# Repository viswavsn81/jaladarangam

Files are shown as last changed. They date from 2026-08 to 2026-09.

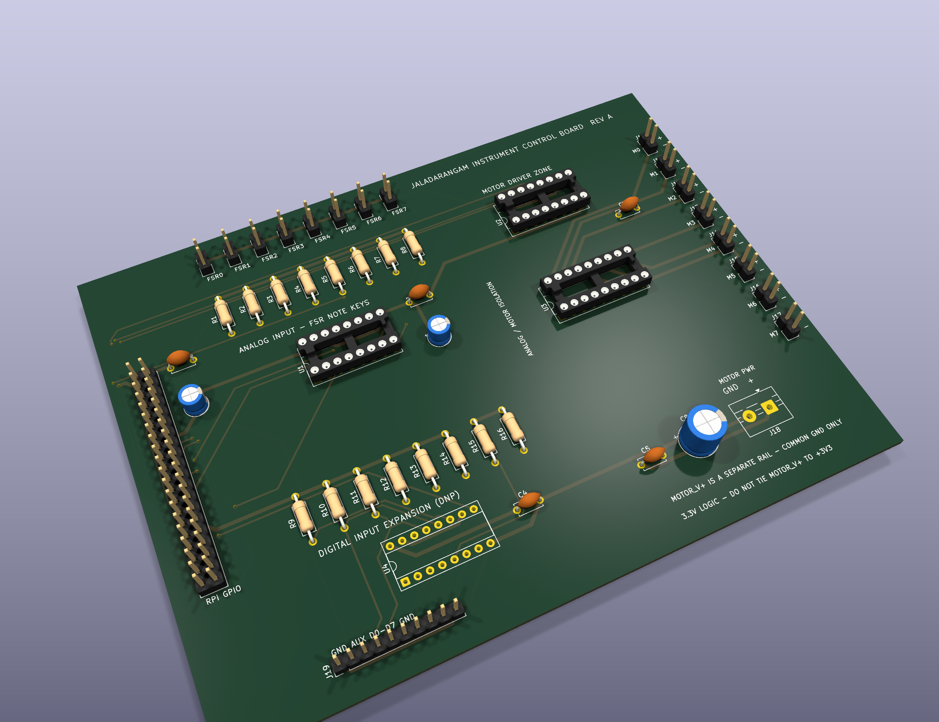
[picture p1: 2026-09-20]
hardware/review/pcb_3d_iso.png

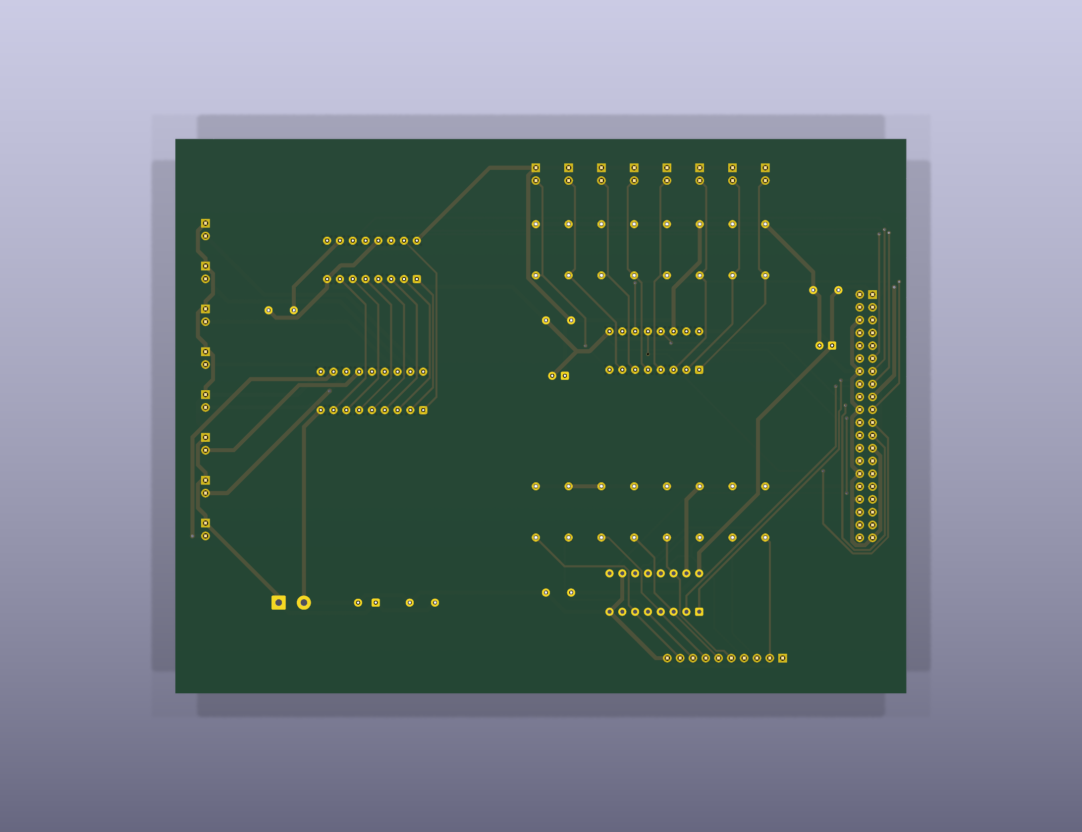
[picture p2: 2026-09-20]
hardware/review/pcb_3d_bottom.png

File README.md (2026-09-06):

# Mindfulness Instrument

A Raspberry Pi 3 project that plays an instrument sample when a sensor is triggered.
Started as a keyboard-spacebar proof of concept (evdev + pygame); the wiring below is
for the real sensor hardware: 8 FSR402 force sensors, one per note key (Sa through
upper Sa), read through an MCP3008 ADC over SPI. An earlier hardware iteration used
2 FSRs plus a SparkFun SoftPot ribbon for continuous glide; that layout was replaced
by the 8 discrete note keys below, and the SoftPot has since been removed entirely.

The project's original design called for two MCP3008 chips sharing one SPI0 bus
(distinguished by chip-select line): **ADC1** for the 8 note-key FSRs, and **ADC2**
for the gamakam/octave-up/octave-down control keys. ADC1 is documented and wired
below and is the only MCP3008 in the current build. **ADC2 was built, found to
have an unresolved hardware fault, and has been fully replaced** by an Arduino
Nano 33 BLE reading the three control keys directly over USB serial — see
[STATUS.md](STATUS.md) for the current project state and [ADC2 (control keys)](#adc2--control-keys)
below for the (now superseded) ADC2 wiring record.

## Hardware

- Raspberry Pi 3 Model B
- 2x MCP3008 8-channel 10-bit ADC (16-pin DIP, SPI interface) — ADC1 (note keys,
  wired) and ADC2 (control keys, being wired)
- 8x FSR402 round force sensor (18mm) — ADC1's discrete note keys, CH0-CH7 =
  Sa, Ri, Ga, Ma, Pa, Da, Ni, Sa' (upper Sa)
- Resistors: 8x 10kΩ (ADC1, one per note-key FSR) — plus 1x 10kΩ per ADC2
  control-key FSR as those get populated
- Breadboard + jumper wires

## Wiring

All physical pin numbers below refer to the Raspberry Pi's 40-pin GPIO header, and were
verified against the official Raspberry Pi pinout and the Microchip MCP3008 datasheet
(DS20001295E) before wiring.

### Pi -> MCP3008 (ADC1)

| Pi physical pin | Signal | MCP3008 pin |
|---|---|---|
| 1 | 3.3V | 16 (VDD) |
| 1 | 3.3V | 15 (VREF) |
| 6 | GND | 14 (AGND) |
| 6 | GND | 9 (DGND) |
| 23 | GPIO11 / SPI0 SCLK | 13 (CLK) |
| 19 | GPIO10 / SPI0 MOSI | 11 (DIN) |
| 21 | GPIO9 / SPI0 MISO | 12 (DOUT) |
| 24 | GPIO8 / SPI0 CE0 | 10 (CS/SHDN) |

MCP3008 pin 1 (CH0) is at the end of the chip marked with a notch/dot — make sure that
end is oriented correctly on the breadboard before inserting.

### Note-key channel assignment (ADC1)

| MCP3008 pin (channel) | Note key |
|---|---|
| 1 (CH0) | Sa |
| 2 (CH1) | Ri |
| 3 (CH2) | Ga |
| 4 (CH3) | Ma |
| 5 (CH4) | Pa |
| 6 (CH5) | Da |
| 7 (CH6) | Ni |
| 8 (CH7) | Sa' (upper Sa) |

All 8 are discrete FSR keys, matching `jaladarangam.py`'s `LIVE_POSITIONS =
set(range(8))`. There is no SoftPot or continuous-glide sensor in the current
hardware — an earlier prototype iteration used a SoftPot ribbon on CH2 for
continuous pitch glide, but that approach was replaced by these 8 discrete FSR
keys and the SoftPot has been physically removed.

### Sensors (voltage dividers into ADC1)

Identical divider pattern for all 8 note-key FSRs:

| Component | Leg/end | Connects to |
|---|---|---|
| Note-key FSR | leg A | 3.3V rail |
| Note-key FSR | leg B | ADC1 channel pin (per the table above) **and** 10kΩ resistor -> GND |

The 10kΩ resistor forms a voltage divider: FSR resistance drops under pressure,
so the sense-node voltage *rises* with force.

## Step-by-step wiring order (ADC1)

1. Power off / unplug the Pi before wiring anything.
2. Seat the MCP3008 across the breadboard's center gap, pin 1 (notch end) toward CH0.
3. Run the 3.3V rail and GND rail down the breadboard from the Pi's pin 1 and pin 6.
4. Wire MCP3008 VDD (16) and VREF (15) to the 3.3V rail; AGND (14) and DGND (9) to the GND rail.
5. Wire the SPI lines: Pi pin 23 -> MCP3008 CLK (13), Pi pin 19 -> DIN (11),
   Pi pin 21 -> DOUT (12), Pi pin 24 -> CS/SHDN (10).
6. Wire each of the 8 note-key FSRs (Sa through Sa', MCP3008 channels CH0-CH7 per
   the channel-assignment table above): one leg to the 3.3V rail, the other leg to
   its assigned MCP3008 channel pin and to one leg of a 10kΩ resistor whose other
   leg goes to the GND rail. Repeat for all 8 keys.
7. Double-check every connection against the tables above before powering the Pi back on.
8. Once wired, enable SPI on the Pi (`sudo raspi-config nonint do_spi 0`) if not already
   enabled, then reboot before trying to read the MCP3008.

## ADC2 (control keys) — SUPERSEDED, kept for historical/wiring reference only

**This entire section describes an abandoned hardware path.** ADC2 was
physically wired per the plan below, then extensively fault-tested (FSR
swaps, pulldown/ground checks, chip-select swaps, physical chip swaps) after
every channel — including one never wired to anything — read an identical
fixed value no matter what changed. That combination of tests pointed at the
MCP3008 chip/circuit itself, not the wiring, so ADC2 was retired rather than
debugged further. **The three control keys (gamakam, octave+, octave-) are
now read by an Arduino Nano 33 BLE over USB serial instead** — see
[STATUS.md](STATUS.md) and `control_keys/control_keys.ino`. No code in this
repo reads ADC2/CE1. The wiring plan below is left intact only as a record
of what was built and why it didn't work, in case the physical MCP3008/
breadboard setup is ever revisited.

ADC2 is a second MCP3008 sharing the same SPI0 bus as ADC1 (same CLK/DIN/DOUT,
same power/ground rails), distinguished by its own hardware chip-select line
(CE1 instead of ADC1's CE0). It carries the three control keys — gamakam,
octave+, octave- — reserved from the original two-chip instrument design.

### Shared bus (Pi -> ADC2)

Identical to ADC1's bus wiring above — these four signals are shared by both
chips; do not re-run separate jumpers from the Pi for these, just tie ADC2's
matching pins onto the same rails/lines ADC1 already uses.

| Pi physical pin | Signal | MCP3008 pin |
|---|---|---|
| 1 | 3.3V | 16 (VDD) |
| 1 | 3.3V | 15 (VREF) |
| 6 | GND | 14 (AGND) |
| 6 | GND | 9 (DGND) |
| 23 | GPIO11 / SPI0 SCLK | 13 (CLK) |
| 19 | GPIO10 / SPI0 MOSI | 11 (DIN) |
| 21 | GPIO9 / SPI0 MISO | 12 (DOUT) |

### ADC2-specific: chip select

| Pi physical pin | Signal | MCP3008 pin |
|---|---|---|
| 26 | GPIO7 / SPI0 CE1 | 10 (CS/SHDN) |

This is distinct from ADC1's chip-select (Pi physical pin 24, GPIO8 / SPI0 CE0)
— CE0 and CE1 are separate hardware-controlled pins, so make sure ADC2's
CS/SHDN goes to physical pin 26 (GPIO7/CE1), not physical pin 24 (GPIO8/CE0),
which is already committed to ADC1.

### Channel assignment (reserved from the original design)

| MCP3008 pin (channel) | Control key | Status |
|---|---|---|
| 1 (CH0) | gamakam | unpopulated — currently a keyboard-spacebar stand-in in software |
| 2 (CH1) | octave+ | unpopulated |
| 3 (CH2) | octave- | unpopulated |
| 4-8 (CH3-CH7) | spare/unused | reserved for future use, not currently assigned |

### Sensors (voltage dividers into ADC2) — apply per channel as each FSR is added

Same pattern as ADC1's note-key FSRs: for whichever of the three control
channels above has an FSR physically attached, wire it as follows. Do **not**
wire a channel this way until an FSR is actually being installed on it —
until then, leave that channel's row in the table above as "unpopulated."

| Component | Leg/end | Connects to |
|---|---|---|
| Control-key FSR | leg A | 3.3V rail |
| Control-key FSR | leg B | ADC2 channel pin (CH0/CH1/CH2 per the table above) **and** 10kΩ resistor -> GND |

### Step-by-step wiring order (ADC2)

1. Power off / unplug the Pi before wiring anything.
2. Seat the second MCP3008 on the breadboard, pin 1 (notch end) toward CH0, same
   orientation convention as ADC1.
3. Tie ADC2's VDD (16) and VREF (15) onto the existing 3.3V rail; AGND (14) and
   DGND (9) onto the existing GND rail (the same rails ADC1 already uses).
4. Tie ADC2's CLK (13), DIN (11), and DOUT (12) onto the same SPI0 SCLK/MOSI/MISO
   lines ADC1 already uses (Pi physical pins 23/19/21) — these lines are shared,
   not duplicated.
5. Wire ADC2's CS/SHDN (10) to Pi physical pin 26 (GPIO7 / SPI0 CE1) — a new,
   ADC2-only line, separate from ADC1's CE0 on physical pin 24.
6. For each control-key FSR you are physically installing now, wire it per the
   voltage-divider table above into its assigned channel; leave any channel with
   no FSR yet unpopulated rather than wiring a dangling divider.
7. Double-check every connection against the tables above before powering the Pi
   back on, and update the status line at the top of this section to reflect
   exactly which channels are now populated.
8. SPI0 is already enabled from the ADC1 setup; no additional `raspi-config`
   step is needed for a second chip on the same bus.

## Software

- `spacebar_instrument.py` — the keyboard-spacebar proof of concept (evdev + pygame),
  kept as a reference/fallback trigger while the sensor wiring above is being built out.
- `samples/guitar_note.wav` — CC0 guitar sample from OpenGameArt.org
  (https://opengameart.org/content/guitar-0), used by the spacebar PoC.
- `read_fsr_raw.py` — prints raw MCP3008 readings for a channel; used to verify a
  sensor's wiring/divider orientation before building anything on top of it.
- `fsr_oscillator.py` — maps FSR1 (CH0) and FSR2 (CH1) each to a persistent sine
  oscillator (pygame.mixer, 48000Hz/1024-sample buffer) whose pitch tracks pressure;
  an interface-level proof of concept, not the final instrument sound.
- `gamaka.py` — the pressure-controlled pitch-bend (gamaka) proof of concept. FSR1
  triggers/bends a D3 guitar pluck, FSR2 triggers/bends a G3 pluck. Samples are
  streamed through a `sounddevice` callback with a variable-rate linear-interpolation
  reader per voice (pygame.mixer can't vary playback speed live, hence the different
  library here vs. the oscillator above). Raw ADC is EMA-smoothed before driving the
  bend; a fresh pluck triggers on the raw touch-threshold crossing, and the bend
  (0 to +40 cents, `rate = 2^(cents/1200)`) tracks the smoothed value continuously,
  including after release, so pitch settles back down instead of snapping.
- `prepare_samples.py` — one-time preprocessing script that derived `d3_pluck.wav`
  and `g3_pluck.wav` from the source samples below.
- `samples/d3_pluck.wav`, `samples/g3_pluck.wav` — derived from
  [`karoryfer.shinyguitar`](https://github.com/sfzinstruments/karoryfer.shinyguitar)
  (CC0 1.0, verified directly against the repo's `LICENSE` file). That library samples
  in whole tones rather than every semitone, so D3 and G3 aren't recorded directly —
  they're derived from the nearest neighbors (Eb3 and Gb3) via a 1-semitone pitch
  shift, resampled to 48000Hz to match this Pi's PipeWire audio graph quantum.
- `jaladarangam.py` — the current real hardware-driven instrument. Reads all 8
  physical note-key FSRs on ADC1 (CH0-CH7 = Sa..Sa'), with raga-selectable
  positional layout (`--raga`), polyphony (up to 8 notes ringing
  independently), mandolin/guitar/flute instrument switching with
  per-instrument envelopes (flute stops promptly on release; mandolin/guitar
  ring through their natural decay), octave-aware jaru (glide) and octave-
  nearest note selection, gamakam/octave+/octave- read from an Arduino Nano
  33 BLE over USB serial (see `control_keys/control_keys.ino`), odukkal
  (pressure-to-pitch-bend, toggleable), attack velocity, the double bass
  drone, a live 3-band EQ, master volume, and dual I2S+headphone output. All
  of the above is controllable via typed stdin commands, a WiFi WebSocket
  server (port 8765), and a Bluetooth Classic SPP connection (no PIN
  pairing) — all three dispatch through the same command layer, both
  network transports run persistently via systemd
  (`systemd/jaladarangam.service`), and both are documented in full in
  **[PROTOCOL.md](PROTOCOL.md)** (the contract for building a remote-control
  app against). Known limitation: a tanpura drone was scoped
  but is **not implemented** (no CC0/permissive-license sample could be
  sourced that was also actually downloadable — a Freesound recording was
  gated behind account login, and a Pixabay mirror of it was blocked by
  Cloudflare bot-protection from this environment's tools). Usage:
  `python3 jaladarangam.py --raga Shankarabharanam`.

### Control-key software support (superseded — now via Arduino Nano, not ADC2)

`jaladarangam.py` reads only ADC1 (CE0) for note keys — no code in this repo
opens or reads ADC2 (CE1) at all, since ADC2 was retired (see above). The
gamakam/octave+/octave- control keys are real hardware today, but read from
an Arduino Nano 33 BLE over USB serial (`poll_nano_values`), not from ADC2 or
any keyboard stand-in. See [STATUS.md](STATUS.md) for the current summary and
`control_keys/control_keys.ino` for the Nano's own firmware.

`gamaka.py`, `read_fsr_raw.py`, and `fsr_oscillator.py` each open a single
spidev bus (ADC1/CE0 only) with no CE1/ADC2 handling, and are unrelated to
`jaladarangam.py`'s Nano integration. The keyboard-based prototypes
(`sliding_window_raga.py`, `gamaka_keyboard.py`, `gamaka_keyboard_mixer.py`)
stand in for control keys with keyboard input (e.g. spacebar for gamakam,
bracket keys for octave up/down) and don't touch spidev at all — these are
separate, earlier scripts, left unchanged.

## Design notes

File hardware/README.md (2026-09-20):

# Jaladarangam Instrument Control Board

KiCad 10 project for the instrument's control board: a Raspberry Pi 3 reads 8
analog FSR note keys through an MCP3008 SPI ADC, and drives 8 vibration motors
through a 74HC595 shift register feeding a ULN2803A Darlington array. A 74HC165
is fitted as a socketed but unpopulated digital-input expansion.

Logic runs at 3.3 V. **MOTOR_V+ is a separate supply rail** sharing only GND
with the logic domain — it is never tied to +3V3.

Board: 145 × 110 mm, 2 layers, through-hole throughout, all four ICs socketed.

## Everything is generated from one file

`scripts/board_spec.py` is the single source of truth: components, pin-to-net
assignments, schematic and PCB placement, design rules and net classes. The
schematic, PCB, project file and BOM are all generated from it, so there is no
second place for the wiring to drift.

Nothing here is hand-edited. To change the board, change `board_spec.py` and
re-run the pipeline.

```
scripts/build.sh     board_spec -> .kicad_pro -> .kicad_sch -> .kicad_pcb -> .dsn
scripts/route.sh     autoroute, import the session, DRC, zone check
scripts/fab.sh       gerbers, drill files, BOM
scripts/make_review.sh   3D renders, 2D layout, silkscreen close-ups -> review/
```

The order in `build.sh` matters. `make_project_file.py` writes the net classes
into the `.kicad_pro`; `gen_pcb.py` then **binds that project to the board**
before saving. A bare `pcbnew.BOARD()` carries KiCad's built-in defaults (one
0.2 mm class), and saving such a board writes those defaults straight over the
project file — which is exactly how the MOTOR_V+ Power class was silently lost
once. `gen_pcb.py` now refuses to write a board whose net classes are wrong.

## Verification

Each stage is checked independently rather than trusted:

| Check | What it proves |
|---|---|
| `board_spec.sanity_check` | No duplicate refs, no single-pad nets, MOTOR_V+ and +3V3 share no pad, divider/driver/aux nets have the right pad counts, every polarity mark agrees with the net on its pad |
| `verify_polarity.py` | Every silkscreen polarity mark sits nearest the pad it names, and that pad carries the net the mark asserts |
| `kicad-cli sch erc` | KiCad's own electrical rules — 0 violations |
| `verify_netlist.py` | KiCad's exported netlist matches `board_spec` pad-for-pad, and every deliberately open pin is accounted for |
| `verify_netclasses.py` | The DSN handed to the router really carries 0.8 mm on the motor rail and 0.4 mm on signals |
| `import_ses.py` | Track widths that actually landed on copper match their net class |
| `kicad-cli pcb drc` | 0 violations, 0 unconnected |
| `verify_zones.py` | Motor and analog copper stayed in their own zones after routing |

## Review images

`review/` is the single home for reviewable output - schematic and board, PDF
and PNG - so the design can be looked at without opening KiCad. It regenerates
with `scripts/make_review.sh`:

| File | What it shows |
|---|---|
| `schematic.pdf` | Full schematic, vector - the one to read properly |
| `schematic.png` | Same sheet at 300 dpi, for a quick look |
| `pcb_routed.pdf` | Routed board, vector |
| `pcb_3d_iso.png` | 3D isometric with component bodies |
| `pcb_3d_top.png` / `pcb_3d_bottom.png` | 3D straight-on, both sides |
| `pcb_2d_layout.png` | 2D layout: both copper layers, silkscreen, outline |
| `pcb_silkscreen.png` | Silkscreen + board outline only, no copper |
| `silk_fsr_headers.png` | Close-up: FSR note-key headers J2-J9 |
| `silk_motor_headers.png` | Close-up: motor headers J10-J17 |
| `silk_motor_power.png` | Close-up: motor supply input J18 |
| `silk_aux_header.png` | Close-up: AUX digital input header J19 |
| `silk_pi_header.png` | Close-up: Raspberry Pi GPIO header J1 |

The silkscreen views plot `F.Silkscreen` and `Edge.Cuts` only, in black and
white - no copper behind the captions, and far better contrast than KiCad's
silkscreen yellow on a white page. `Edge.Cuts` is kept purely for orientation.

Crops come from the footprints themselves (`dump_regions.py` reads the board),
not hard-coded rectangles, so they stay correct if placement changes. KiCad's
`--page-size-mode 2` SVG carries a viewBox in board millimetres, so a crop is
just a narrowed viewBox rather than pixel arithmetic.

The schematic is one A2 sheet. PDF is the primary form because it stays vector
and a dense sheet reads at any zoom; the 300 dpi PNG is there for convenience.
The PNG step is driven by the PDF's actual page count, so extra sheets would be
exported as `schematic_p1.png`, `schematic_p2.png` rather than silently lost.

3D renders need the 3D model packages, which the lite AppImage omits;
`kienv.sh` points `KICAD10_3DMODEL_DIR` at a full KiCad extract when one is
present and warns if it is not. U4 renders as bare pads because KiCad hides
3D models for DNP parts - its socket is still fitted.

## Toolchain

No root, no paid services.

- **KiCad 10.0.6**, official AppImage in `/home/pyru/opt/kicad10`. Provides
  `kicad-cli` and a bundled `python3.11` with `pcbnew`.
- **FreeRouting 2.4.1** headless CLI in `/home/pyru/opt/freerouting`, via a
  Specctra DSN → SES round-trip.
- **Temurin JDK 25** in `/home/pyru/opt/jdk25` — FreeRouting's jar is
  class-file 69 and the system JDK is 21.

`scripts/kienv.sh` wires these together and keeps KiCad's config and library
tables inside `hardware/.kicad-config/`, so builds do not depend on any
developer's `~/.config/kicad` state.

## Layout

Signal flow runs left to right, with the two noisy domains held apart:

```
Pi header | analog input zone | << 14 mm empty corridor >> | motor driver zone
(left edge) (FSR headers top    (nothing routed across it   (motor headers
             edge, pulldowns,     but GND and +3V3)          right edge,
             MCP3008)                                        supply bottom)
                 |
   74HC165 expansion block (DNP) along the bottom edge
```

Every off-board connector is edge-accessible and captioned on silkscreen:
`FSR0-7`, `M0-7`, `MOTOR PWR`, `GND AUX D0-D7 GND`, `RPi GPIO`.

## Notes for assembly

- Fit all four IC sockets, **including U4's** — the 74HC165 itself is the only
  DNP part, so the expansion can be populated later with no rework. Its
  pulldowns (R9-R16) and header (J19) are populated.
- J19 is a 1×10: pins 1 and 10 are GND, pins 2-9 are D0-D7.
- Each FSR header is `+3V3` on pin 1, channel node on pin 2. The 10 k pulldown
  is on-board; the FSR forms the upper leg of the divider.
- Each motor header is `MOTOR_V+` on pin 1 (marked `+`), the ULN2803A output
  on pin 2 (marked `-`). Pin 1 is the rectangular pad, with the L-shaped silk
  corner beside it. Wire the motor's positive lead to `+`.
- J18 is marked `+` (MOTOR_V+) and `GND`. Getting it backwards would put the
  motor rail onto the board's ground net.
- `fab/bom.csv` includes the sockets and the off-board parts;
  `fab/bom_kicad.csv` is KiCad's own export of the schematic parts only.

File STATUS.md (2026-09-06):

# Project status (as of 2026-09-06)

A running snapshot of where this project actually is, for picking work back
up cleanly later. Hardware/wiring specifics live in `README.md`; the network
control JSON contract lives in `PROTOCOL.md`. This file is the "what's done,
what's not, what's next" summary.

## Hardware

- **ADC1 (MCP3008, SPI CE0)**: all 8 note keys (Sa through upper Sa, CH0-CH7)
  physically wired with real FSR402 sensors and confirmed working.
- **ADC2 is gone.** The originally-planned second MCP3008 for the three
  control keys had an unresolved hardware fault (every channel - including
  one never wired to anything - read an identical fixed value regardless of
  wiring, grounding, or which physical chip/chip-select line was used). It
  has been **fully replaced** by an Arduino Nano 33 BLE over USB serial,
  reading its own three analog FSRs directly: `A0`=gamakam, `A1`=octave+,
  `A2`=octave- (firmware: `control_keys/control_keys.ino`). No ADC2/CE1
  code remains in `jaladarangam.py`.

## Software (`jaladarangam.py`)

- **Polyphony**: up to 8 notes ring independently (was strictly
  monophonic). A key's own re-pluck replaces only its own prior voice.
- **Octave-nearest note selection** on normal plucks: Ri/Ga/Ma/Pa/Da/Ni land
  in whichever octave (default, one up, or one down) is nearest the last
  note played. **Sa and upper Sa are deliberately excluded** from this -
  they already have two dedicated keys (key 1 / key 8), and applying
  nearest-pitch there too would flip the traditional Ni->Sa cadence to
  resolve upward instead of down (the leading-tone-to-tonic gap is always
  the largest "improvement" nearest-pitch could find, so no distance-based
  rule can fix the Sa-adjacent case without also breaking this one - this
  was worked through explicitly rather than guessed). The manual
  octave+/octave- keys remain the override for any other case.
- **Odukkal** (pressure-to-pitch-bend while a key is held and ringing):
  toggle with `o`+Enter (stdin) or `toggle_odukkal` (network), default OFF.
  One-euro-filtered per voice, additive on top of jaru/octave-shift state.
- **Attack velocity**: always active (not gated by the odukkal toggle) -
  press speed scales pluck loudness.
- **Per-instrument envelope**: mandolin/guitar are "plucked" (ring through
  natural decay regardless of release - unchanged, original behavior).
  Flute is "sustained" - release stops the note promptly with a short
  (50ms) click-free fade instead of playing out its full recorded length.
  True crossfaded sample looping for the sustain portion was considered
  and deliberately not implemented (see `jaladarangam.py`'s module
  docstring for why - the samples' natural sustain region has real
  vibrato/breath variation that makes a blind loop point risky).
- **Network control**: every toggle/config command (drone, instrument
  source, EQ, dual output, odukkal, volume) is a standalone function
  callable from anywhere, dispatched identically regardless of transport.
  Two transports, both running now, both documented in full in
  `PROTOCOL.md`:
  - **WiFi**: WebSocket server on port 8765.
  - **Bluetooth**: Classic SPP/RFCOMM, standard Serial Port Profile UUID,
    "Just Works" pairing (no PIN). Built on BlueZ's own D-Bus API
    (`dbus-python` + PyGObject's `GLib`), not PyBluez (confirmed
    unmaintained - see `PROTOCOL.md`'s implementation notes).
  - Both transports run persistently via a `systemd --user` service
    (`systemd/jaladarangam.service`, with lingering enabled) - survives
    reboots, no terminal session required. stdin control still works
    identically alongside both.
  - Validated end-to-end with a real Android phone: paired with no PIN,
    connected via a generic SPP terminal app ("Serial Bluetooth
    Terminal"), sent `{"cmd": "toggle_drone"}`, confirmed the drone
    turned on and a simultaneously-connected WebSocket client saw the
    same state change broadcast immediately.

## Explicitly NOT yet done

- **Tanpura drone**: scoped early on, never implemented. No CC0/permissive-
  license sample could be found that was also actually downloadable
  (a Freesound CC0 recording was gated behind account login; a Pixabay
  mirror of it was blocked by Cloudflare bot-protection from available
  tooling). No `toggle_tanpura` command exists anywhere - there's no
  feature behind it to expose.
- **The Android app itself**: not started. `PROTOCOL.md` is written as its
  complete spec (every command, exact fields, the state-push shape, both
  transports) - manual testing so far has used a generic SPP terminal app
  and a Python WebSocket script standing in for it, not a real app.
- **Jaru direction coverage**: only Sa->Ri has been extensively
  bench-tested against real hardware; other key-to-key jaru pairs and
  octave-down landings are implemented (and now exercised more, thanks to
  polyphony/octave-nearest testing) but not as thoroughly verified.
- **Attack-velocity calibration**: the counts/sec thresholds
  (`VELOCITY_MIN/MAX_COUNTS_PER_SEC`) were recalibrated once against real
  press data during testing but are still a rough fit, not a precisely
  tuned curve - worth revisiting by ear if velocity response feels off.
- **CPU headroom**: checked informally under active multi-key play
  (~20% of one core on the Pi 3, comfortable) - never stress-tested with
  literally all 8 keys held simultaneously plus drone plus dual output,
  since that requires more hands/hardware than one person has.

## Next session: start here

**Build the Android app against `PROTOCOL.md`.** This session's entire
WiFi+Bluetooth effort was specifically to enable that, both transports are
now validated end-to-end with real (if generic) clients, and the protocol
doc is written to be a complete, standalone spec for exactly this. This is
offered as a recommendation, not a decision made on the user's behalf - say
if tanpura sourcing (or something else) should actually come first.

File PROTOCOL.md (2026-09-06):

# jaladarangam.py network control protocol

This is the contract for any client (Android app, browser dev console, test
script, Bluetooth SPP terminal app) controlling `jaladarangam.py` remotely.
The **same JSON command set and state-push shape** applies over both
transports below - only how the bytes get to/from the process differs.

## Transport 1: WiFi (WebSocket)

- URL: `ws://<pi-ip>:8765`
- The Pi's LAN IP is **not fixed** in this document on purpose - run
  `hostname -I` on the Pi to get its current address, or check the
  `[network] WebSocket server listening on ...` line the instrument prints
  at startup. Port `8765` is fixed.
- No authentication, no TLS. This is a local-network-only control channel -
  do not expose port 8765 outside your LAN (e.g. via router port-forwarding).
- Every message, both directions, is a single JSON object per WebSocket
  text frame (not newline-delimited, not batched).

## Transport 2: Bluetooth (Classic SPP / RFCOMM)

- Device name shown while scanning/pairing: **`Jaladarangam`** (this Pi's
  Bluetooth alias - not its hostname).
- Service: standard Serial Port Profile, UUID `00001101-0000-1000-8000-00805f9b34fb`,
  RFCOMM channel 1. Any generic Bluetooth SPP terminal app (Android or
  otherwise) that connects "by UUID" (the normal way - `BluetoothDevice.
  createRfcommSocketToServiceRecord(SPP_UUID)` on Android) finds this
  automatically; you should not need to hardcode channel 1, though it's
  fixed if a client needs it.
- **Pairing is "Just Works" - no PIN or passkey needed on either side.**
  The Pi registers a `NoInputNoOutput` pairing agent, which is what
  triggers Secure Simple Pairing's Just Works mode. From a phone: scan for
  Bluetooth devices, tap "Jaladarangam", confirm the pairing prompt (there
  is nothing to type or compare) - that's the whole flow.
- The Pi is **always discoverable and pairable** while `jaladarangam.py` is
  running (no discoverability timeout is set) - this is a local demo
  device, not a device meant to hide from casual scanning.
- **Framing is newline-delimited JSON**, one JSON object per line (`\n`-
  terminated) - unlike a WebSocket, a raw RFCOMM socket has no built-in
  per-message framing, so this project uses the same line-per-message
  convention already used for the Arduino Nano's serial link. Any SPP
  terminal app that sends/displays plain text with normal line endings
  works fine; do not send multiple JSON objects on one line, and do not
  split one JSON object across multiple lines.
- No authentication beyond standard Bluetooth pairing/bonding. Once
  paired, a bonded device can reconnect without re-pairing (normal
  Bluetooth behavior) - unpair from your phone's Bluetooth settings to
  revoke that.

## Client -> server: commands (both transports)

Every command is `{"cmd": "<name>", ...fields}`. Unknown `cmd` values or
malformed JSON get back a `type: "error"` reply (see below) - they never
crash the connection.

| cmd | fields | effect |
|---|---|---|
| `toggle_drone` | none | Turns the double bass drone on (starting at octave C#1) if off, or cycles it to the next octave if already on - mirrors stdin `b`. |
| `stop_drone` | none | Turns the drone off - mirrors stdin `c`. |
| `toggle_dual_output` | none | Toggles the headphone-jack output on/off alongside the main I2S output - mirrors stdin `s`. |
| `cycle_instrument` | none | Advances to the next instrument (mandolin -> guitar -> flute -> mandolin) - mirrors stdin `i`. |
| `set_instrument` | `value`: one of `"mandolin"`, `"guitar"`, `"flute"` | Directly selects an instrument (no stdin equivalent - stdin only cycles). Invalid `value` returns an error and changes nothing. |
| `toggle_odukkal` | none | Toggles odukkal (pressure-to-pitch-bend) on/off - mirrors stdin `o`. |
| `set_eq` | `band`: one of `"bass"`, `"mid"`, `"treble"`; `delta`: whole number (int, or a float with no fractional part e.g. `2.0`) | Adjusts the named EQ band by `delta` steps of 2dB each (matches the granularity of stdin's `b+`/`b-`/`m+`/`m-`/`t+`/`t-` - `delta` is a STEP COUNT, not raw dB). `delta: 1` == one `b+`; `delta: -3` == three `b-` in one call. If the resulting gain would clip the output, the command is rejected (logged on the Pi as `[EQ] CEILING REACHED`) and no state changes - you will not see a state push confirming a change that didn't happen. |
| `set_volume` | `value`: number, `0.0`-`1.0` | Sets master volume directly. Out-of-range values are clamped, not rejected. |
| `adjust_volume` | `delta`: whole number (int, or integer-valued float) | Adjusts master volume by `delta` steps of 0.1 each (matches stdin `v+`/`v-`). |
| `get_state` | none | Requests an immediate state reply (see below) with no side effects - useful right after reconnecting if you don't want to wait, though you also get state automatically on connect (see below). |

Fields not listed for a command are ignored, not rejected.

### Not in this protocol: tanpura

There is no `toggle_tanpura` (or similar) command. `jaladarangam.py` never
implemented a tanpura drone at all (a suitable license-clean, downloadable
sample could not be sourced - see the module docstring) - there is no
feature behind such a command to expose. Do not build UI for it.

## Server -> client: state pushes

After **every command that actually changes something** - whether it
arrived over WiFi, Bluetooth, or the Pi's local stdin console - the server
pushes the full current state to **every connected client on both
transports**. A change made from a Bluetooth-connected phone is seen
immediately by a WebSocket-connected client too, and vice versa:

```json
{
  "type": "state",
  "state": {
    "instrument": "flute",
    "sa_note": "C4",
    "octave_shift": 0,
    "drone": {"on": true, "octave": 1},
    "eq": {"bass": 16.0, "mid": 0.0, "treble": 0.0},
    "odukkal": true,
    "dual_output": false,
    "volume": 0.7
  }
}
```

(Over Bluetooth SPP, this same JSON is followed by a `\n` - see the framing
note above. Over WebSocket, it's the entire content of one text frame.)

Field meanings:

- `instrument`: `"mandolin"` | `"guitar"` | `"flute"` - the currently active sample source.
- `sa_note`: the current tonic (Sa) note name, e.g. `"C4"` - changes automatically when `instrument` changes (unless `--sa` was passed on the command line at startup, in which case it's fixed).
- `octave_shift`: integer, `-2` to `+2` - set by the physical octave+/octave- hardware keys (Arduino Nano A1/A2), **not controllable over this protocol** - included here for display only.
- `drone.on`: boolean. `drone.octave`: `1`, `2`, or `null` when off.
- `eq.bass` / `eq.mid` / `eq.treble`: current gain in dB for each band (can be negative).
- `odukkal`: boolean - whether pressure-to-pitch-bend is currently enabled.
- `dual_output`: boolean - whether the headphone jack is active alongside I2S.
- `volume`: float, `0.0`-`1.0`.

**You always get a state push immediately on connecting**, before sending
anything - so a client that just opened the connection (or reconnected
after a drop) sees accurate current state without needing to send
`get_state` first. `get_state` exists for polling mid-session if you want
it, not as a required handshake step.

A command that does **not** change anything (an unknown `cmd`, a rejected
`set_eq` that would clip, an invalid `set_instrument` value) produces **no
state push** - only the direct error reply below, sent to the client that
issued it.

## Server -> client: errors

Sent only to the client whose command caused the error - never broadcast:

```json
{"type": "error", "message": "invalid instrument 'trumpet', must be one of ('mandolin', 'guitar', 'flute')"}
```

Common causes: malformed JSON, missing `cmd` field, unknown `cmd`, an
invalid `band`/`instrument` value, a non-numeric or fractional `delta`/
`value`, or an EQ change that would clip the output.

## Running persistently (systemd)

`jaladarangam.py` (both transports, plus stdin) runs as a `systemd --user`
service on the Pi (`~/.config/systemd/user/jaladarangam.service`, also
checked into this repo at `systemd/jaladarangam.service`), with lingering
enabled (`loginctl enable-linger pyru1`) so it starts at boot without
needing an interactive login and restarts automatically on failure. Common
commands (run on the Pi, as the `pyru1` user - no `sudo` needed for these):

```
systemctl --user status jaladarangam.service    # is it running?
systemctl --user restart jaladarangam.service   # e.g. after editing the .py
journalctl --user-unit=jaladarangam.service -f  # live logs (PLUCK/JARU/etc.)
```

### Bluetooth troubleshooting: rfkill

The very first time Bluetooth was used on this Pi, the adapter was
rfkill **soft-blocked** (`Powered` couldn't even be set to true until
unblocked - `cat /sys/class/rfkill/rfkill*/soft`, `1` means blocked).
`systemd-rfkill` persists the unblocked state across reboots automatically
once fixed, so this shouldn't recur - but if Bluetooth ever silently stops
working again and `bluetoothctl show` reports `Powered: no`, check rfkill
state first before assuming a code problem:

```
cat /sys/class/rfkill/rfkill*/soft   # 0 = unblocked, 1 = blocked
echo 0 | sudo tee /sys/class/rfkill/rfkillN/soft   # unblock the bluetooth one
```

## Implementation notes (why these libraries)

- **WiFi**: `websockets` (installed via `sudo apt install python3-websockets`
  - not pip, since this system's Python is externally-managed per PEP 668).
- **Bluetooth**: `dbus-python` + PyGObject's `GLib` (both already present on
  Raspberry Pi OS), talking directly to BlueZ's own D-Bus API
  (`org.bluez.ProfileManager1`, `org.bluez.AgentManager1`) - **not**
  PyBluez. PyBluez is packaged for Debian (`python3-bluez`) but that
  package is literally PyBluez's last-ever upstream release (0.23,
  ~2018) with no real maintenance since. The older `sdptool`/`hciconfig`
  approach some PyBluez-era tutorials use doesn't work on this system's
  BlueZ at all (`bluetoothd` runs without the legacy `--compat` flag it
  requires). The RFCOMM socket I/O itself uses only Python's built-in
  `socket` module (`AF_BLUETOOTH`/`BTPROTO_RFCOMM`), which needs no
  extra package at all.
- `NETWORK_COMMANDS` and `_dispatch_command` in `jaladarangam.py` are the
  single dispatch layer both transports use - a command's *behavior* is
  defined exactly once, regardless of which transport (or stdin) it
  arrived through.
- **A real gotcha worth knowing if this ever needs touching again**: the
  file descriptor BlueZ hands over via `Profile1.NewConnection`'s D-Bus
  call is in **non-blocking mode** - that flag lives on the underlying
  kernel file description (inherited from how `bluetoothd` itself uses
  the socket), not something `socket.socket(fileno=...)` resets just by
  wrapping it. Without an explicit `sock.setblocking(True)` right after
  wrapping it, the first `sendall()` raises `BlockingIOError(EAGAIN)`
  immediately - which looked, from a phone's SPP terminal app, exactly
  like "pairs fine, connects, then silently disconnects within the same
  second, every single time," with `bluetoothd`'s own logs showing
  nothing wrong. Confirmed live via verbose fd/errno logging during
  development before landing on this fix.

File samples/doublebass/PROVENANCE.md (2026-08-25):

# Double bass drone samples - provenance

Source: University of Iowa Electronic Music Studios, Musical Instrument
Samples database - https://theremin.music.uiowa.edu/MISdoublebass2012.html
(the 2012 recordings, which include the sulC low-C-extension string; the
older MISdoublebass.html set only goes down to E1 and doesn't cover C#1).

License: per the MIS database's own usage statement
(https://theremin.music.uiowa.edu/MIS.html), these recordings "may be
downloaded and used for any projects, without restrictions." Same source
and license as samples/guitar_placeholder.

Articulation: pizzicato (plucked), mf (mezzo-forte) dynamic, mono AIFF -
matches the plucked-string character of the rest of the instrument.

Source files downloaded:
- `Bass.pizz.sulC.mf.C1Eb1.mono.aif` - a chromatic run of C1, C#1, D1, Eb1
  concatenated in one file, not individual notes.
- `Bass.pizz.sulA.mf.C2B2.mono.aif` - chromatic run of all 12 notes C2
  through B2.

Processing:
1. Split into individual notes via onset detection (short-time RMS
   envelope, threshold crossings merged with a >=2.5s minimum gap - the
   very low fundamentals here have slow, complex envelopes that produce
   spurious extra crossings at a shorter gap). Segment count and order
   cross-checked against the chromatic sequence implied by each
   filename's range (4 notes for C1Eb1, 12 for C2B2) - both matched
   exactly. Only the 2nd segment of each file (C#1, C#2) was kept; see
   `samples/_src_doublebass_csharp1.wav` and `_src_doublebass_csharp2.wav`
   in the parent samples/ dir for the isolated raw extracts (44100Hz, as
   recorded, pitch not yet corrected).
2. Pitch measured via mandolin_audio.detect_pitch (the same autocorrelation
   approach gamaka.py uses for its portamento) - C#1 measured 34.53Hz,
   C#2 measured 68.58Hz, both ~6-18 cents flat of exact equal-temperament
   (C#1=34.65Hz, C#2=69.30Hz, A4=440). Corrected via
   mandolin_audio.linear_resample (the same varispeed resampler used
   throughout this project, e.g. prepare_samples.py), same technique as
   gamaka.py's bend-to-exact-pitch, not assumed already in tune. Verified
   after correction: both land within 3 cents of target.
3. Resampled to 48000Hz to match this project's audio pipeline.
4. Looped for continuous sustain: a real pizzicato note decays rather than
   sustaining forever, so there's no way to loop it without *some* seam.
   The attack transient (~0.2s) and the last ~0.3s (mostly silence/noise
   floor) are trimmed, then the tail is crossfaded into the head over
   0.25s (linear crossfade) - the standard sampler technique for looping
   a decaying recording. This does not achieve bit-exact continuity, only
   a perceptually smoothed transition; if the seam turns out to be
   audible in practice, first things to try are a longer crossfade or a
   different loop-start point (see `prepare_doublebass.py`).
5. Normalized to peak amplitude 0.45 (the loop region, with the loud
   attack trimmed off, is much quieter than the raw pluck) - comparable
   to the mandolin samples' own peak range (~0.35-0.5), so the drone
   isn't lost once mixed under the melodic notes.

File naming: `csharp{1,2}_mf.wav`, mono, 48000Hz, matching this project's
existing sample-set conventions.

Regenerate with: `python3 prepare_doublebass.py` (reads the two
`_src_doublebass_*.wav` files, writes the two files in this directory).

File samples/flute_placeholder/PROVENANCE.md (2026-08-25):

# Flute placeholder samples - provenance

Source: University of Iowa Electronic Music Studios, Musical Instrument
Samples database - https://theremin.music.uiowa.edu/MISaltoflute.html
Same source/license as samples/guitar_placeholder and
samples/doublebass.

License: per the MIS database's own usage statement
(https://theremin.music.uiowa.edu/MIS.html), "may be downloaded and
used for any projects, without restrictions."

Instrument: **Alto Flute**, not standard C Flute - chosen deliberately
for its lower/mellower register, as a possible fix for mandolin's
mids/highs sounding shrill. Vibrato articulation (the only articulation
this instrument was recorded with in this database), mf (mezzo-forte)
dynamic, matching this project's "mid dynamic" convention elsewhere.

Source files downloaded (4, covering the full recorded range):
- `_src_flute_G3B3.aif`, `_src_flute_C4B4.aif`, `_src_flute_C5B5.aif`,
  `_src_flute_C6G6.aif` - each a chromatic run of multiple notes
  concatenated (same pattern as guitar_placeholder and the double bass
  source files), not individual-note recordings.

Processing (`prepare_flute.py`):
1. Split into individual notes via onset detection (short-time RMS
   envelope, threshold crossings). Segment count cross-checked against
   the chromatic span implied by each filename (5/12/12/8 notes) -
   all 4 files matched exactly once C6G6 was given a longer minimum
   onset-gap (2.5s vs 1.0s for the others - its notes have longer
   decay/reverb tails at that register, which produced one spurious
   extra onset at the shorter gap).
2. Pitch measured via mandolin_audio.detect_pitch per note - but with a
   *narrow* search window (+-~2.5 semitones) centered on that note's own
   expected equal-temperament pitch, not one broad window for the whole
   file. This was necessary, not just careful: with a broad window,
   several higher notes came back autocorrelation-locked onto a strong
   overtone instead of the true fundamental (e.g. bb4 measured at
   461.5Hz, off by over an octave) - flutes have much weaker
   fundamentals relative to their overtones than the plucked strings
   this pitch detector was originally validated against (mandolin,
   guitar). With the narrowed per-note window, all 37 notes measured
   within 37 cents of their expected pitch, montonically consistent
   note-to-note - not corrected/retuned, left as measured, matching
   this project's existing convention for guitar_placeholder (documented
   there as "10-40 cents flat... not corrected").
3. Resampled to 48000Hz mono via mandolin_audio.linear_resample.

Not normalized: peak levels vary considerably across the set (0.094 to
0.991), a real characteristic of the source recording (breath pressure/
projection naturally varies by register) - left as-is, matching
guitar_placeholder's own precedent of not normalizing per-note levels.
If some notes sound noticeably quieter/louder than others in practice,
that's the reason; per-note normalization would be the fix.

Coverage: 37 notes, G3 through G6, zero gaps, no files excluded (all 4
source files' onset counts matched their expected note count exactly).
This is a considerably narrower and higher range than guitar_placeholder
(E2-B5) or the mandolin's own register (sa=C#4 - see gamaka.py) - see
gamaka_keyboard_mixer.py's own reporting for whether this range
comfortably covers a given raga/tonic/octave-shift combination; it will
NOT cover an octave-down shift from a Sa around A3-C#4, since G3
(196Hz) sits close to or above where such a shift would land.

File naming: `<note>_mf.wav`, lowercase scientific pitch notation with
flats (e.g. `gb4_mf.wav` = G-flat 4), mono, 48000Hz - matching
guitar_placeholder's exact convention.

Regenerate with: `python3 prepare_flute.py`.

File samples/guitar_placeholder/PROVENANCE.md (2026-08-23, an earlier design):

# Guitar placeholder samples - provenance

Source: University of Iowa Electronic Music Studios, Musical Instrument
Samples database - https://theremin.music.uiowa.edu/MISguitar.html

License: per the MIS database's own usage statement
(https://theremin.music.uiowa.edu/MIS.html), these recordings "may be
downloaded and used for any projects, without restrictions." Verified
directly against that page's text before downloading, independent of
this being a stated assumption.

Dynamic: mf (mezzo-forte) only, downloaded as mono AIFF.

Processing: each source file is a chromatic run of multiple notes
concatenated (e.g. `Guitar.mf.sulE.E2B2.mono.aif` contains E2 through B2,
not a single note), not individual note recordings. Split into individual
notes via librosa onset detection, with note count cross-checked against
the range implied by the filename, and every split segment's pitch
independently verified via librosa's pyin against the expected chromatic
note (flagging anything off by more than 50 cents as a likely
mis-split - none were).

Coverage: 44 notes, E2 through B5, zero gaps. Consistently tuned ~10-40
cents flat of standard A440 equal temperament across the whole set (this
is the real guitar's actual tuning at recording time, not a detection
error - confirmed by the fact that every chromatic interval between
adjacent notes measures as a clean 100 cents). Not corrected/retuned -
matches this project's existing convention (see gamaka.py) of measuring
real pitch from the actual audio rather than assuming standard tuning.

3 of the 15 downloaded source files had onset-detection count mismatches
and were excluded rather than trusted: Guitar.mf.sulA.C3B3.mono.aif,
Guitar.mf.sulD.D3B3.mono.aif, Guitar.mf.sulG.C5Db5.mono.aif. Their note
ranges are fully covered by other, cleanly-split files, so exclusion
caused no coverage gap.

File naming: `<note>_mf.wav`, note in lowercase scientific pitch notation
with flats (e.g. `gb4_mf.wav` = G-flat 4). Sample rate 48000Hz mono,
matching this project's existing pipeline (gamaka.py SAMPLE_RATE).

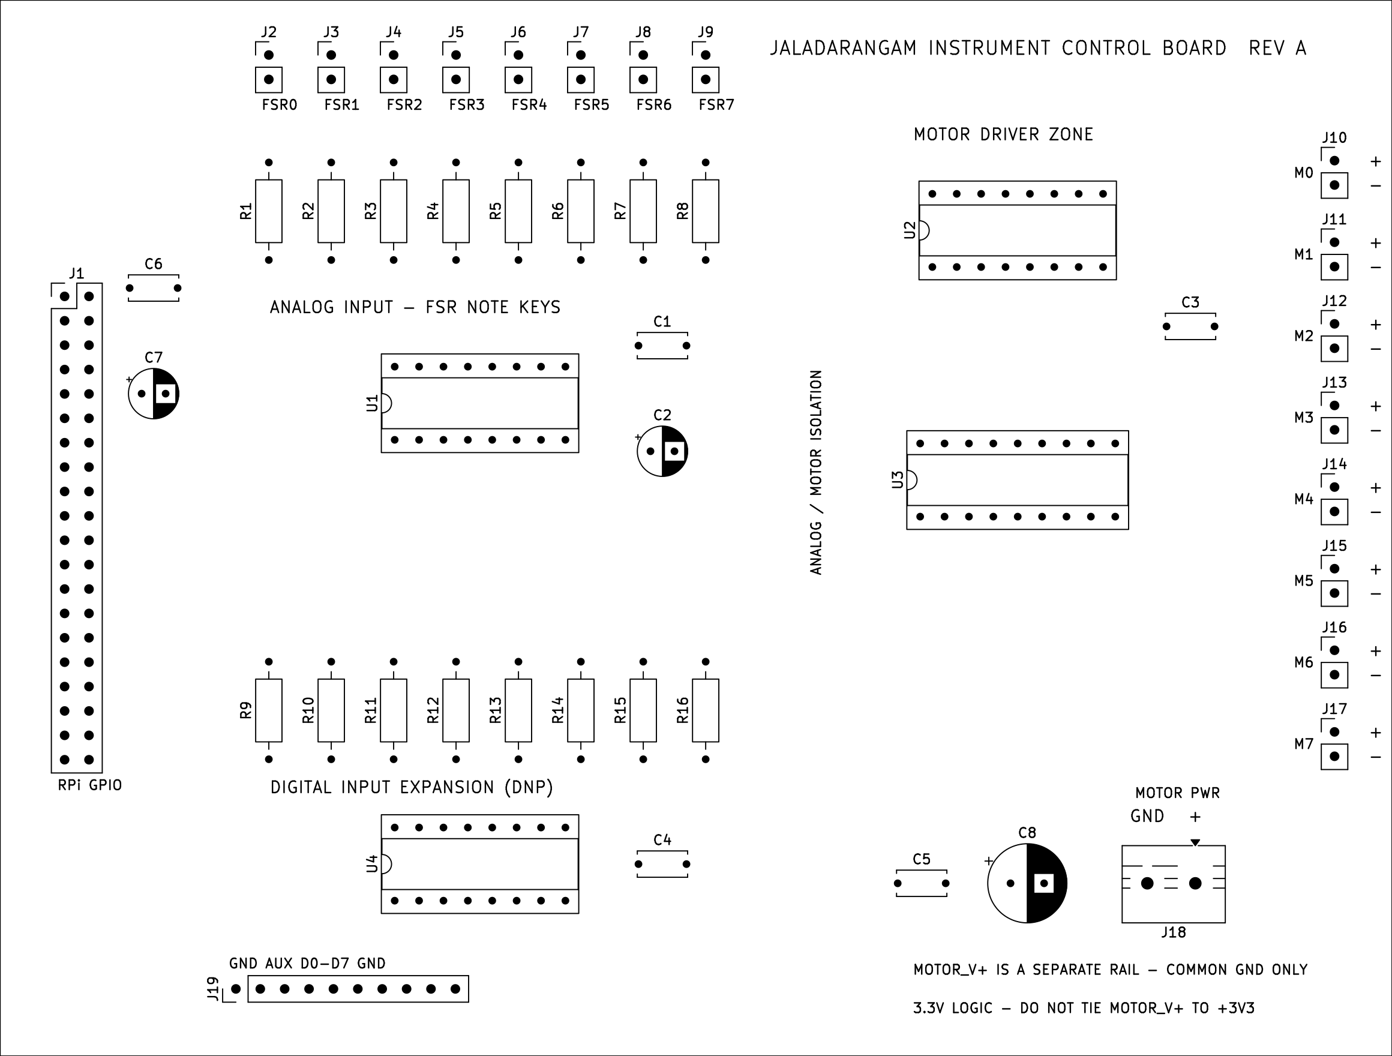
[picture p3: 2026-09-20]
hardware/review/pcb_silkscreen.png

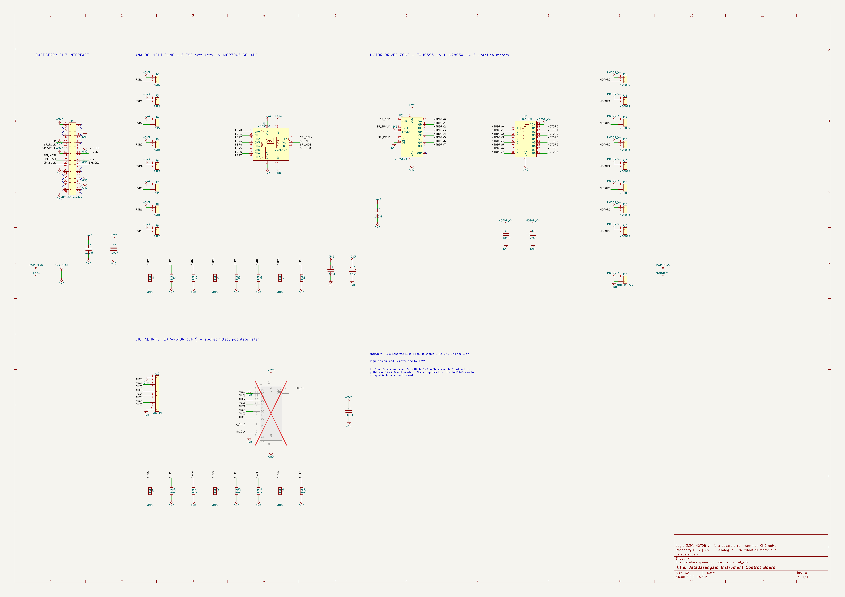
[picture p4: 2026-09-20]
hardware/review/schematic.png

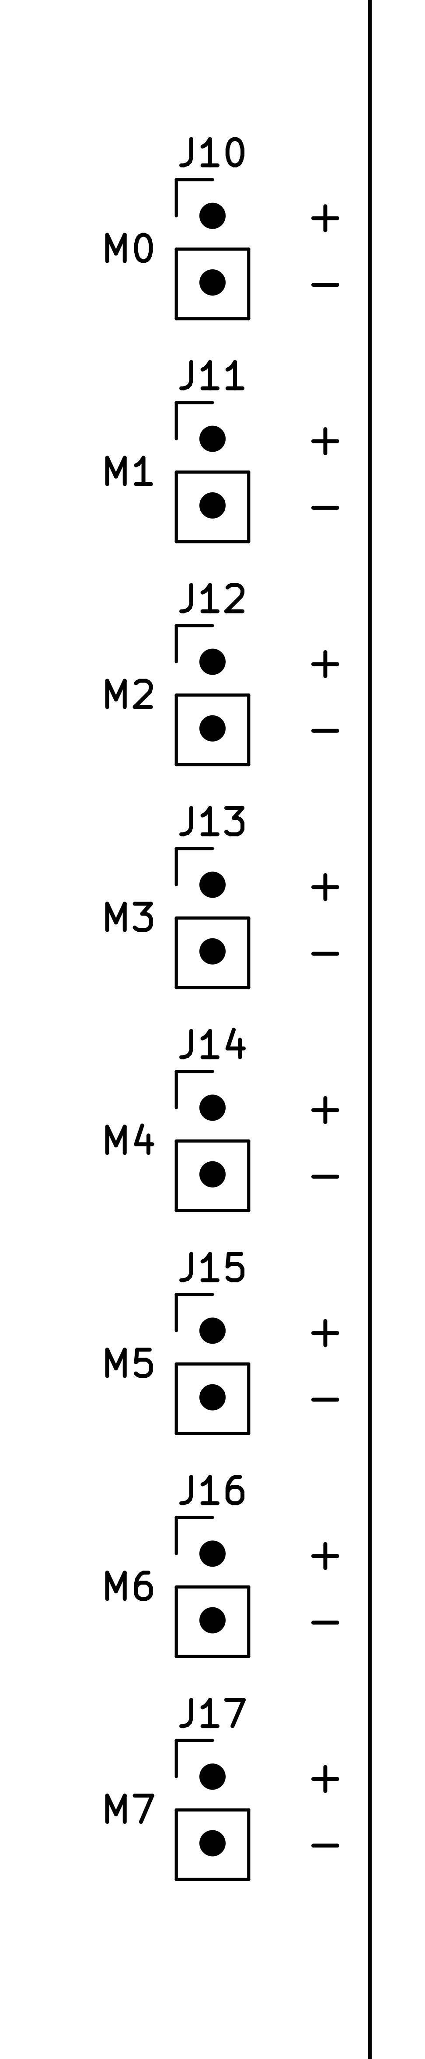
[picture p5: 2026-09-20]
hardware/review/silk_motor_headers.png

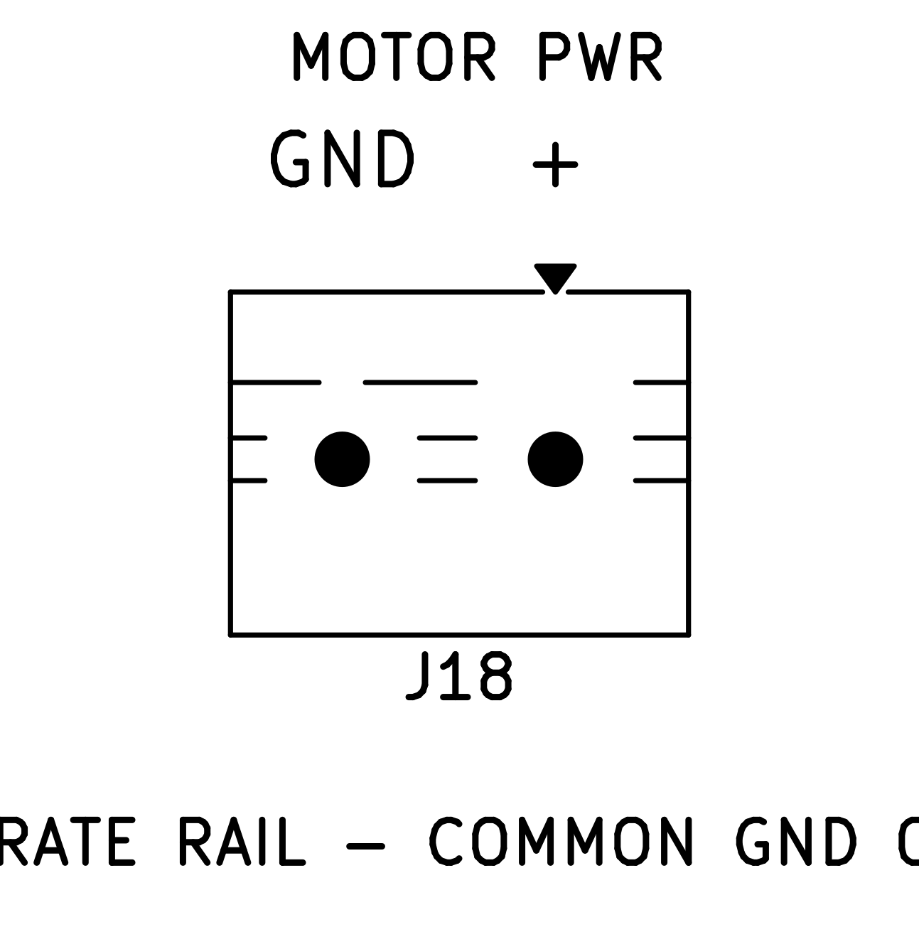
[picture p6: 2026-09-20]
hardware/review/silk_motor_power.png

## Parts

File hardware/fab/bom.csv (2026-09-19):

Item | Refs | Qty | Value | Footprint | DNP | Notes
Board part | J1 | 1 | RPi_GPIO_2x20 | Connector_PinHeader_2.54mm:PinHeader_2x20_P2.54mm_Vertical |  | Raspberry Pi 3 40-pin GPIO header
Board part | U1 | 1 | MCP3008 | Package_DIP:DIP-16_W7.62mm_Socket |  | 8-channel 10-bit SPI ADC (socketed)
Board part | R1,R2,R3,R4,R5,R6,R7,R8,R9,R10,R11,R12,R13,R14,R15,R16 | 16 | 10k | Resistor_THT:R_Axial_DIN0207_L6.3mm_D2.5mm_P10.16mm_Horizontal |  | FSR divider pulldown, channel 0
Board part | J2 | 1 | FSR0 | Connector_PinHeader_2.54mm:PinHeader_1x02_P2.54mm_Vertical |  | Off-board FSR note key 0
Board part | J3 | 1 | FSR1 | Connector_PinHeader_2.54mm:PinHeader_1x02_P2.54mm_Vertical |  | Off-board FSR note key 1
Board part | J4 | 1 | FSR2 | Connector_PinHeader_2.54mm:PinHeader_1x02_P2.54mm_Vertical |  | Off-board FSR note key 2
Board part | J5 | 1 | FSR3 | Connector_PinHeader_2.54mm:PinHeader_1x02_P2.54mm_Vertical |  | Off-board FSR note key 3
Board part | J6 | 1 | FSR4 | Connector_PinHeader_2.54mm:PinHeader_1x02_P2.54mm_Vertical |  | Off-board FSR note key 4
Board part | J7 | 1 | FSR5 | Connector_PinHeader_2.54mm:PinHeader_1x02_P2.54mm_Vertical |  | Off-board FSR note key 5
Board part | J8 | 1 | FSR6 | Connector_PinHeader_2.54mm:PinHeader_1x02_P2.54mm_Vertical |  | Off-board FSR note key 6
Board part | J9 | 1 | FSR7 | Connector_PinHeader_2.54mm:PinHeader_1x02_P2.54mm_Vertical |  | Off-board FSR note key 7
Board part | U2 | 1 | 74HC595 | Package_DIP:DIP-16_W7.62mm_Socket |  | 8-bit serial-in parallel-out shift register (socketed)
Board part | U3 | 1 | ULN2803A | Package_DIP:DIP-18_W7.62mm_Socket |  | 8-channel Darlington driver array (socketed)
Board part | J10 | 1 | MOTOR0 | Connector_PinHeader_2.54mm:PinHeader_1x02_P2.54mm_Vertical |  | Off-board vibration motor 0
Board part | J11 | 1 | MOTOR1 | Connector_PinHeader_2.54mm:PinHeader_1x02_P2.54mm_Vertical |  | Off-board vibration motor 1
Board part | J12 | 1 | MOTOR2 | Connector_PinHeader_2.54mm:PinHeader_1x02_P2.54mm_Vertical |  | Off-board vibration motor 2
Board part | J13 | 1 | MOTOR3 | Connector_PinHeader_2.54mm:PinHeader_1x02_P2.54mm_Vertical |  | Off-board vibration motor 3
Board part | J14 | 1 | MOTOR4 | Connector_PinHeader_2.54mm:PinHeader_1x02_P2.54mm_Vertical |  | Off-board vibration motor 4
Board part | J15 | 1 | MOTOR5 | Connector_PinHeader_2.54mm:PinHeader_1x02_P2.54mm_Vertical |  | Off-board vibration motor 5
Board part | J16 | 1 | MOTOR6 | Connector_PinHeader_2.54mm:PinHeader_1x02_P2.54mm_Vertical |  | Off-board vibration motor 6
Board part | J17 | 1 | MOTOR7 | Connector_PinHeader_2.54mm:PinHeader_1x02_P2.54mm_Vertical |  | Off-board vibration motor 7
Board part | J18 | 1 | MOTOR_PWR | TerminalBlock:TerminalBlock_MaiXu_MX126-5.0-02P_1x02_P5.00mm |  | Separate motor supply input (V+ / GND)
Board part | U4 | 1 | 74HC165 | Package_DIP:DIP-16_W7.62mm_Socket | DNP | 8-bit parallel-in shift register (socketed, DNP)
Board part | J19 | 1 | AUX_IN | Connector_PinHeader_2.54mm:PinHeader_1x10_P2.54mm_Vertical |  | Auxiliary digital input header (GND, D0..D7, GND)
Board part | C1,C3,C4,C6,C5 | 5 | 100nF | Capacitor_THT:C_Disc_D5.0mm_W2.5mm_P5.00mm |  | U1 VDD decoupling
Board part | C2,C7 | 2 | 10uF | Capacitor_THT:CP_Radial_D5.0mm_P2.50mm |  | MCP3008 VREF/VDD bulk
Board part | C8 | 1 | 220uF | Capacitor_THT:CP_Radial_D8.0mm_P3.50mm |  | Motor supply bulk reservoir
Socket | for U1,U2,U4 | 3 | DIP-16 socket, 7.62mm | Package_DIP:DIP-16_W7.62mm_Socket |  | 16-pin 0.3in DIP IC socket - fit the socket even where the IC is DNP.
Socket | for U3 | 1 | DIP-18 socket, 7.62mm | Package_DIP:DIP-18_W7.62mm_Socket |  | 18-pin 0.3in DIP IC socket - fit the socket even where the IC is DNP.
Off-board | FSR0-FSR7 | 8 | Force-sensing resistor |  |  | Note key sensor, wired to J2-J9. Forms the upper leg of each divider against the on-board 10k pulldown.
Off-board | M0-M7 | 8 | Vibration motor |  |  | Wired to J10-J17. Positive lead to the header's MOTOR_V+ pin, negative to the ULN2803A output pin.
Off-board | PSU | 1 | Motor supply |  |  | Separate supply into J18, sized for 8 motors. Shares only GND with the 3.3V logic domain.

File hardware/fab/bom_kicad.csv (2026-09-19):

Refs | Value | Footprint | Qty | Description | DNP
C1,C3-C6 | 100nF | Capacitor_THT:C_Disc_D5.0mm_W2.5mm_P5.00mm | 5 | Pi 3V3 rail decoupling,U1 VDD decoupling,U2 VCC decoupling,U4 VCC decoupling,ULN2803A COM rail decoupling
C2,C7 | 10uF | Capacitor_THT:CP_Radial_D5.0mm_P2.50mm | 2 | MCP3008 VREF/VDD bulk,Pi 3V3 rail bulk
C8 | 220uF | Capacitor_THT:CP_Radial_D8.0mm_P3.50mm | 1 | Motor supply bulk reservoir
J1 | RPi_GPIO_2x20 | Connector_PinHeader_2.54mm:PinHeader_2x20_P2.54mm_Vertical | 1 | Raspberry Pi 3 40-pin GPIO header
J2 | FSR0 | Connector_PinHeader_2.54mm:PinHeader_1x02_P2.54mm_Vertical | 1 | Off-board FSR note key 0
J3 | FSR1 | Connector_PinHeader_2.54mm:PinHeader_1x02_P2.54mm_Vertical | 1 | Off-board FSR note key 1
J4 | FSR2 | Connector_PinHeader_2.54mm:PinHeader_1x02_P2.54mm_Vertical | 1 | Off-board FSR note key 2
J5 | FSR3 | Connector_PinHeader_2.54mm:PinHeader_1x02_P2.54mm_Vertical | 1 | Off-board FSR note key 3
J6 | FSR4 | Connector_PinHeader_2.54mm:PinHeader_1x02_P2.54mm_Vertical | 1 | Off-board FSR note key 4
J7 | FSR5 | Connector_PinHeader_2.54mm:PinHeader_1x02_P2.54mm_Vertical | 1 | Off-board FSR note key 5
J8 | FSR6 | Connector_PinHeader_2.54mm:PinHeader_1x02_P2.54mm_Vertical | 1 | Off-board FSR note key 6
J9 | FSR7 | Connector_PinHeader_2.54mm:PinHeader_1x02_P2.54mm_Vertical | 1 | Off-board FSR note key 7
J10 | MOTOR0 | Connector_PinHeader_2.54mm:PinHeader_1x02_P2.54mm_Vertical | 1 | Off-board vibration motor 0
J11 | MOTOR1 | Connector_PinHeader_2.54mm:PinHeader_1x02_P2.54mm_Vertical | 1 | Off-board vibration motor 1
J12 | MOTOR2 | Connector_PinHeader_2.54mm:PinHeader_1x02_P2.54mm_Vertical | 1 | Off-board vibration motor 2
J13 | MOTOR3 | Connector_PinHeader_2.54mm:PinHeader_1x02_P2.54mm_Vertical | 1 | Off-board vibration motor 3
J14 | MOTOR4 | Connector_PinHeader_2.54mm:PinHeader_1x02_P2.54mm_Vertical | 1 | Off-board vibration motor 4
J15 | MOTOR5 | Connector_PinHeader_2.54mm:PinHeader_1x02_P2.54mm_Vertical | 1 | Off-board vibration motor 5
J16 | MOTOR6 | Connector_PinHeader_2.54mm:PinHeader_1x02_P2.54mm_Vertical | 1 | Off-board vibration motor 6
J17 | MOTOR7 | Connector_PinHeader_2.54mm:PinHeader_1x02_P2.54mm_Vertical | 1 | Off-board vibration motor 7
J18 | MOTOR_PWR | TerminalBlock:TerminalBlock_MaiXu_MX126-5.0-02P_1x02_P5.00mm | 1 | Separate motor supply input (V+ / GND)
J19 | AUX_IN | Connector_PinHeader_2.54mm:PinHeader_1x10_P2.54mm_Vertical | 1 | Auxiliary digital input header (GND, D0..D7, GND)
R1-R16 | 10k | Resistor_THT:R_Axial_DIN0207_L6.3mm_D2.5mm_P10.16mm_Horizontal | 16 | AUX input pulldown 0,AUX input pulldown 1,AUX input pulldown 2,AUX input pulldown 3,AUX input pulldown 4,AUX input pulldown 5,AUX input pulldown 6,AUX input pulldown 7,FSR divider pulldown, channel 0,FSR divider pulldown, channel 1,FSR divider pulldown, channel 2,FSR divider pulldown, channel 3,FSR divider pulldown, channel 4,FSR divider pulldown, channel 5,FSR divider pulldown, channel 6,FSR divider pulldown, channel 7
U1 | MCP3008 | Package_DIP:DIP-16_W7.62mm_Socket | 1 | 8-channel 10-bit SPI ADC (socketed)
U2 | 74HC595 | Package_DIP:DIP-16_W7.62mm_Socket | 1 | 8-bit serial-in parallel-out shift register (socketed)
U3 | ULN2803A | Package_DIP:DIP-18_W7.62mm_Socket | 1 | 8-channel Darlington driver array (socketed)
U4 | 74HC165 | Package_DIP:DIP-16_W7.62mm_Socket | 1 | 8-bit parallel-in shift register (socketed, DNP) | DNP

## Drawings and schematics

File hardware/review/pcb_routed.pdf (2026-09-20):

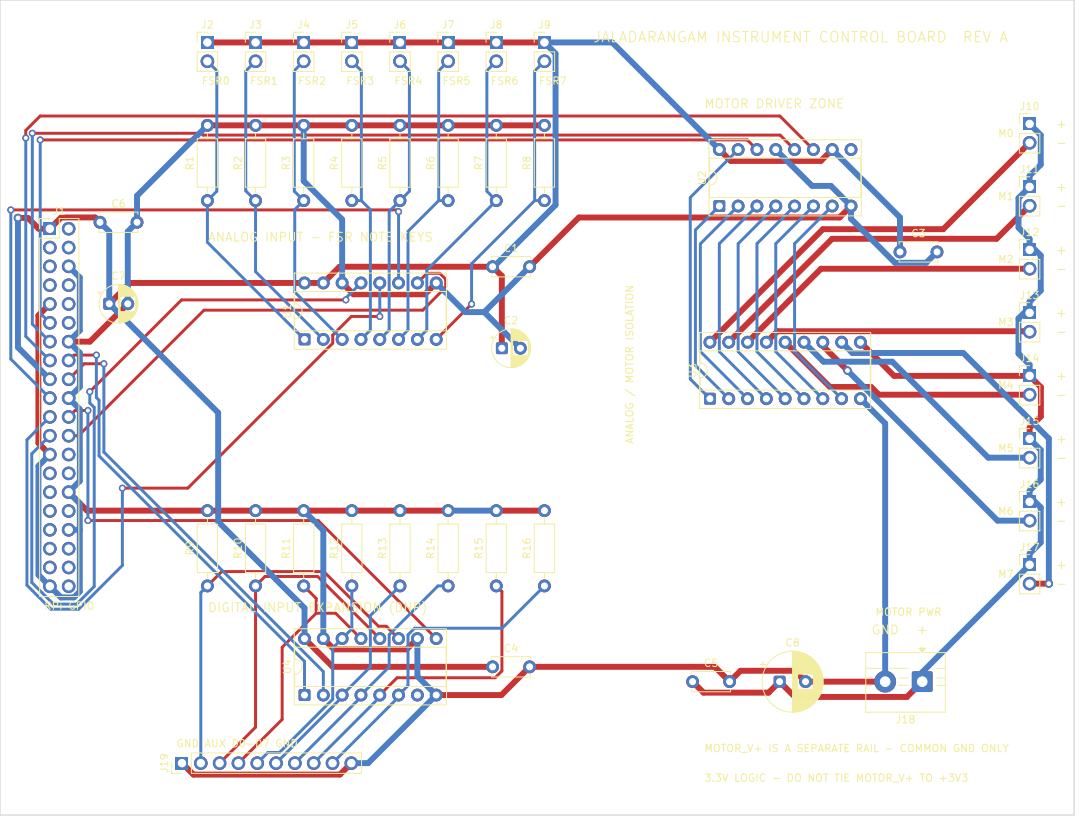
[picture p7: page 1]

JALADARANGAM INSTRUMENT CONTROL BOARD REV A

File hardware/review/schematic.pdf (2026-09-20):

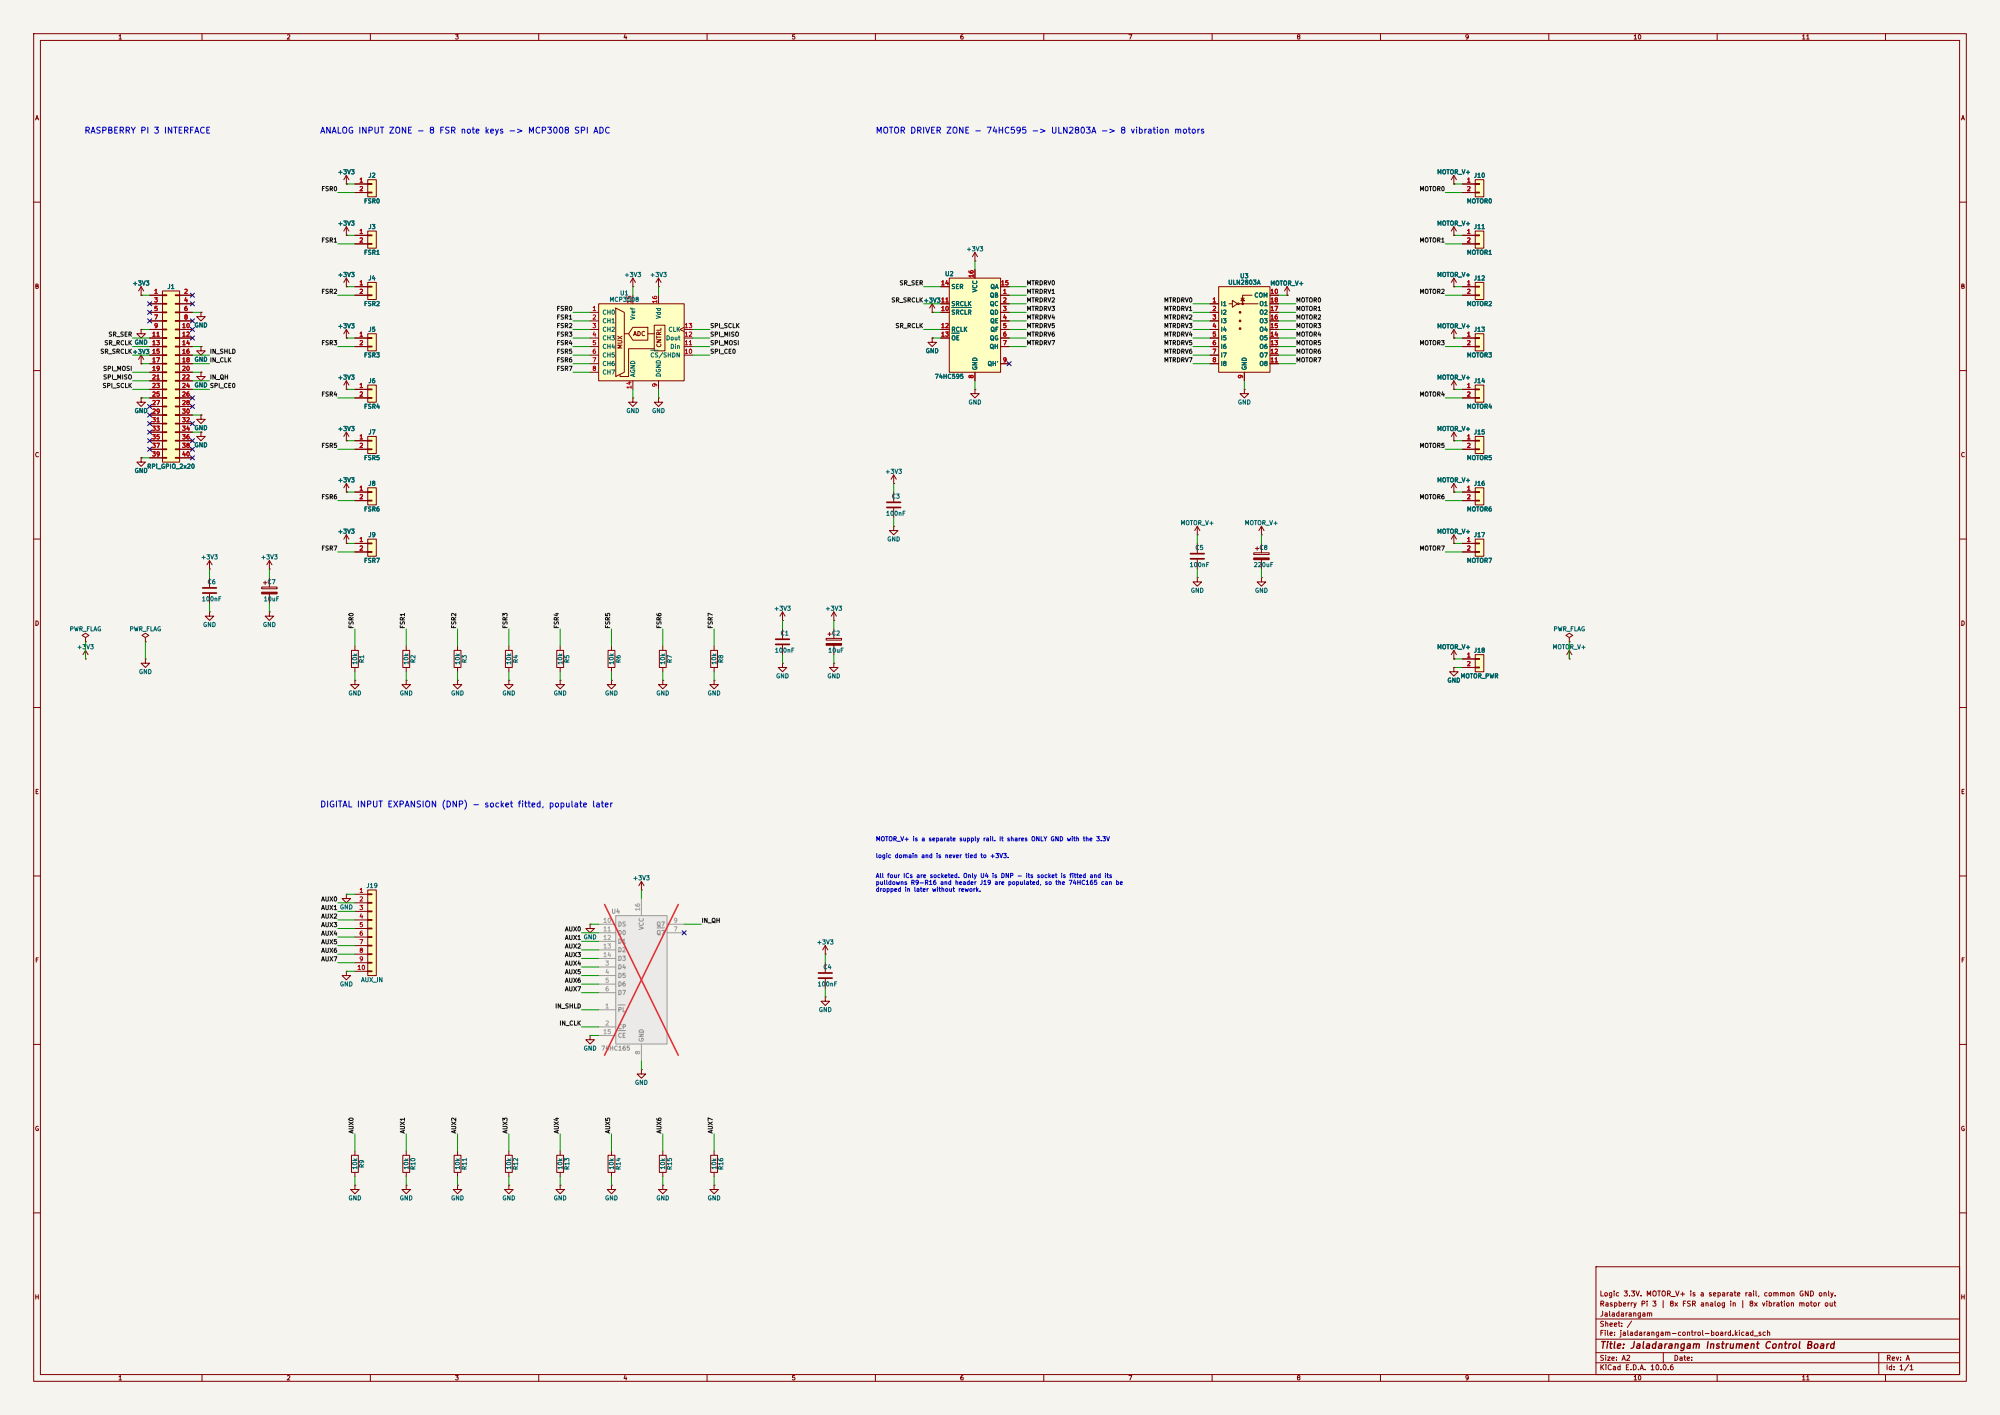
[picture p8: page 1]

ANALOG INPUT ZONE - 8 FSR note keys -> MCP3008 SPI ADC

MOTOR DRIVER ZONE - 74HC595 -> ULN2803A -> 8 vibration motors

SRCLR 10 SRCLK 11 RCLK 12 OE 13

9 CS/SHDN 10 Din 11 Dout 12 CLK 13 AGND 14 Vref 15 Vdd 16U1 MCP3008 GND
FSR2

AUX1 DIGITAL INPUT EXPANSION (DNP) - socket fitted, populate later

logic domain and is never tied to +3V3. MOTOR_V+ is a separate supply rail. It shares ONLY GND with the 3.3V

All four ICs are socketed. Only U4 is DNP - its socket is fitted and its pulldowns R9-R16 and header J19 are populated, so the 74HC165 can be dropped in later without rework.

Logic 3.3V. MOTOR_V+ is a separate rail, common GND only.
Raspberry Pi 3 | 8x FSR analog in | 8x vibration motor out
Jaladarangam
Sheet: /
File: jaladarangam-control-board.kicad_sch
Title: Jaladarangam Instrument Control Board

Size: A2 | Rev: A
KiCad E.D.A. 10.0.6 | Id: 1/1

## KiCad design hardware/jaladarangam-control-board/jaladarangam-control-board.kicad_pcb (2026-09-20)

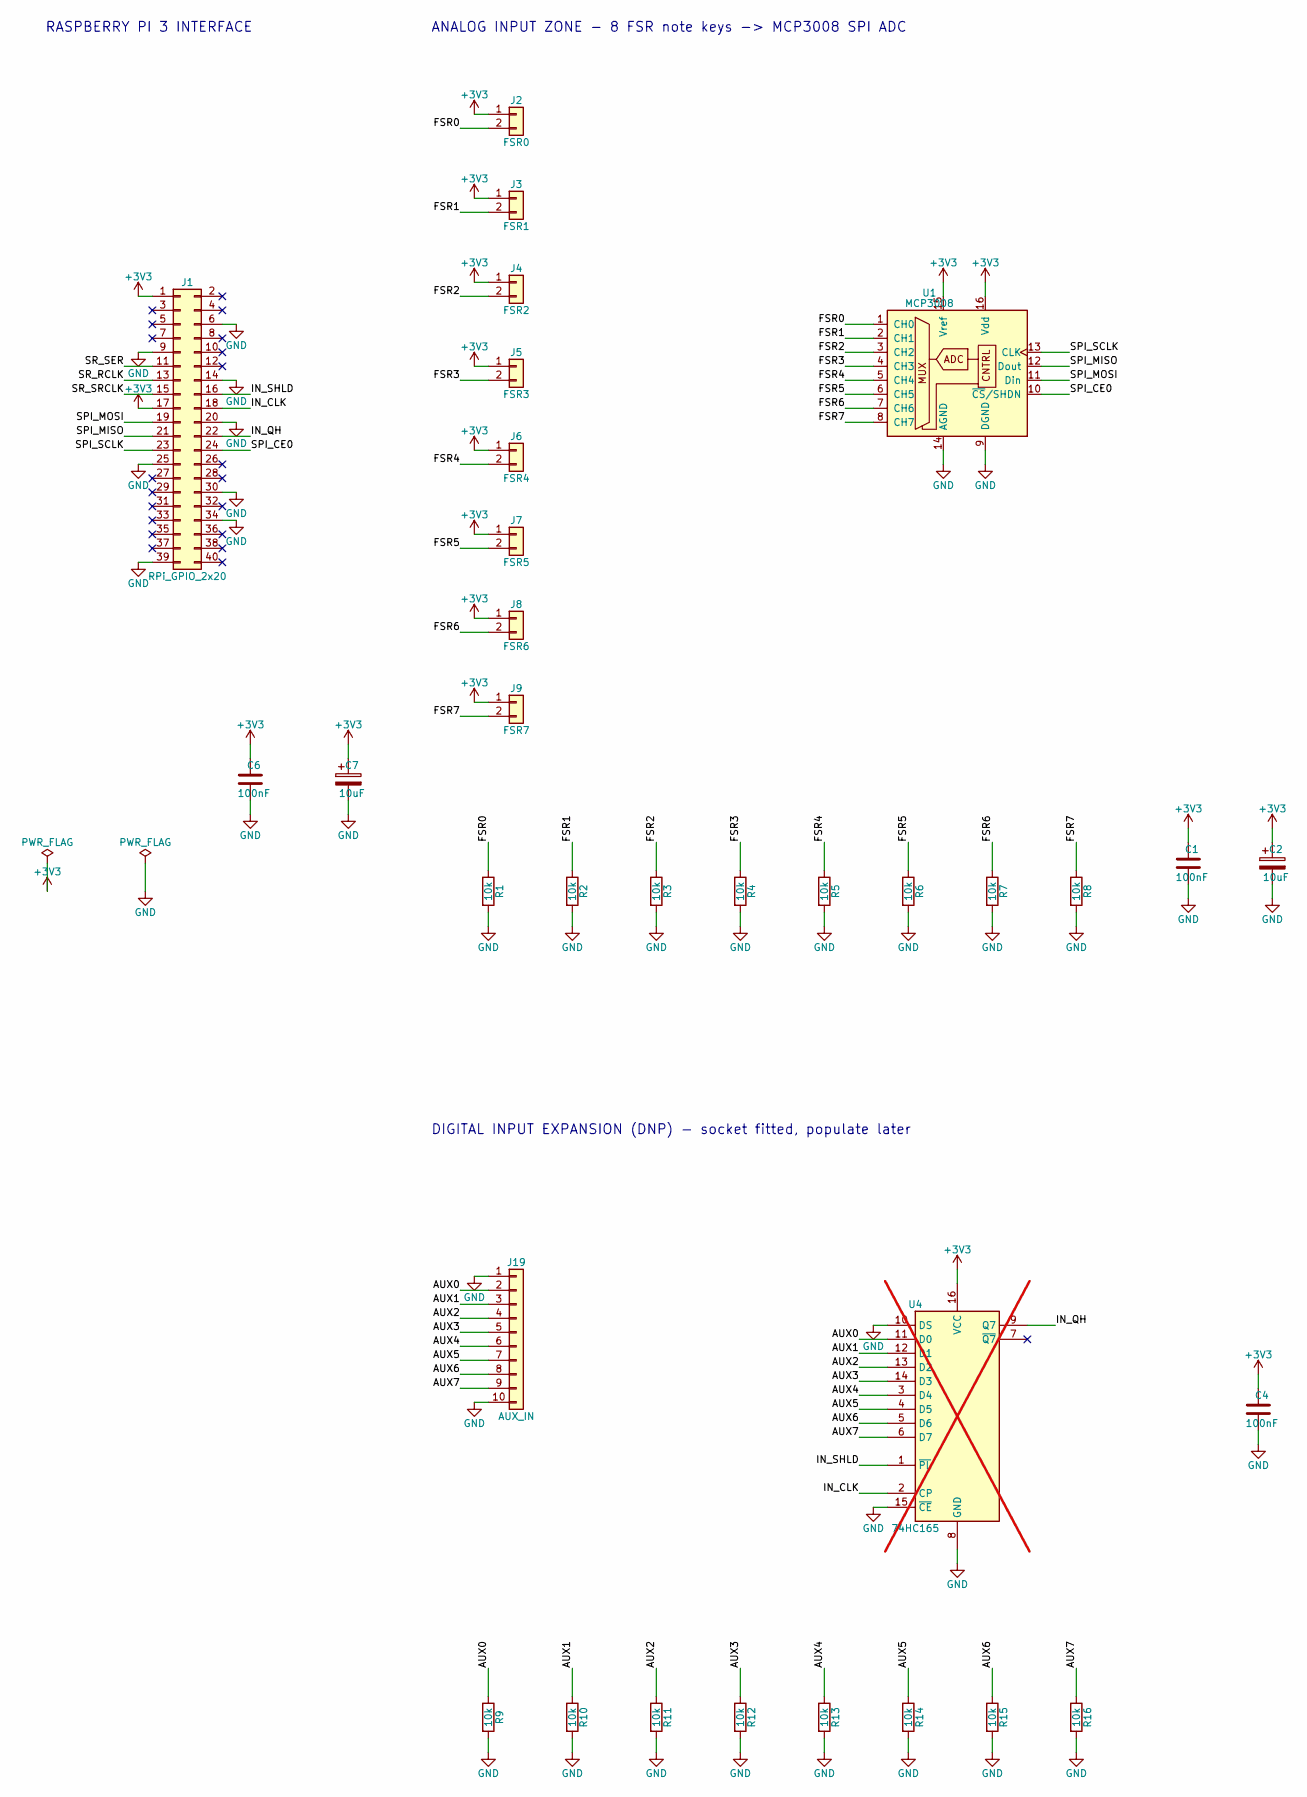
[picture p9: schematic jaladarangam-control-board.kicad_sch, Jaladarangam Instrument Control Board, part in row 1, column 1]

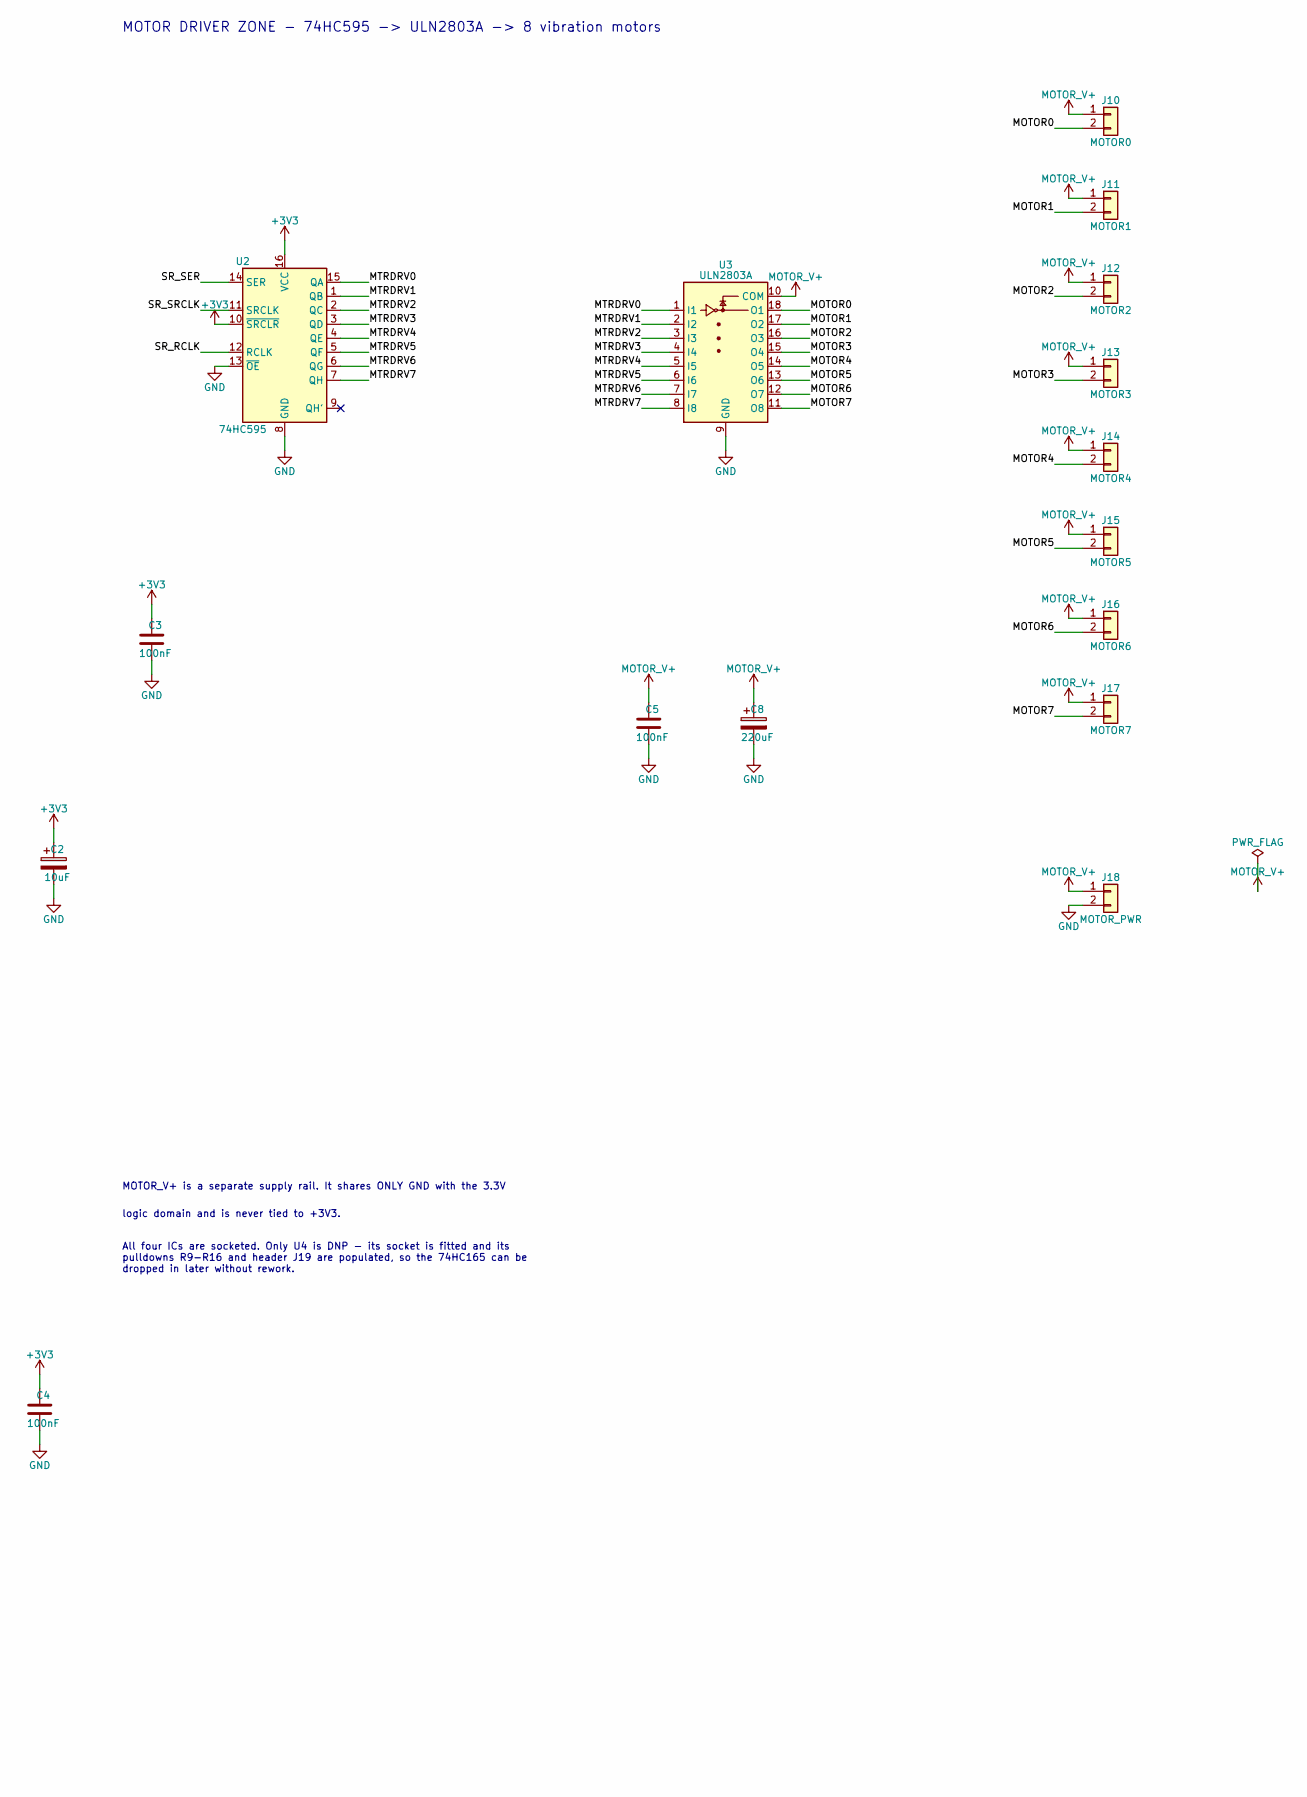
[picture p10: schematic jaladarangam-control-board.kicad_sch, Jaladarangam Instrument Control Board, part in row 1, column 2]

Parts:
C1, C3, C4, C5, C6: 100nF; C_Disc_D5.0mm_W2.5mm_P5.00mm
C2, C7: 10uF; CP_Radial_D5.0mm_P2.50mm
C8: 220uF; CP_Radial_D8.0mm_P3.50mm
J1: RPi_GPIO_2x20; PinHeader_2x20_P2.54mm_Vertical
J2: FSR0; PinHeader_1x02_P2.54mm_Vertical
J3: FSR1; PinHeader_1x02_P2.54mm_Vertical
J4: FSR2; PinHeader_1x02_P2.54mm_Vertical
J5: FSR3; PinHeader_1x02_P2.54mm_Vertical
J6: FSR4; PinHeader_1x02_P2.54mm_Vertical
J7: FSR5; PinHeader_1x02_P2.54mm_Vertical
J8: FSR6; PinHeader_1x02_P2.54mm_Vertical
J9: FSR7; PinHeader_1x02_P2.54mm_Vertical
J10: MOTOR0; PinHeader_1x02_P2.54mm_Vertical
J11: MOTOR1; PinHeader_1x02_P2.54mm_Vertical
J12: MOTOR2; PinHeader_1x02_P2.54mm_Vertical
J13: MOTOR3; PinHeader_1x02_P2.54mm_Vertical
J14: MOTOR4; PinHeader_1x02_P2.54mm_Vertical
J15: MOTOR5; PinHeader_1x02_P2.54mm_Vertical
J16: MOTOR6; PinHeader_1x02_P2.54mm_Vertical
J17: MOTOR7; PinHeader_1x02_P2.54mm_Vertical
J18: MOTOR_PWR; TerminalBlock_MaiXu_MX126-5.0-02P_1x02_P5.00mm
J19: AUX_IN; PinHeader_1x10_P2.54mm_Vertical
R1, R2, R3, R4, R5, R6, R7, R8, R9, R10, R11, R12, R13, R14, R15, R16: 10k; R_Axial_DIN0207_L6.3mm_D2.5mm_P10.16mm_Horizontal
U1: MCP3008; DIP-16_W7.62mm_Socket
U2: 74HC595; DIP-16_W7.62mm_Socket
U3: ULN2803A; DIP-18_W7.62mm_Socket
U4: 74HC165; DIP-16_W7.62mm_Socket; not fitted

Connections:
+3V3: C1.1, C2.1, C3.1, C4.1, C6.1, C7.1, J1.1, J1.17, J2.1, J3.1, J4.1, J5.1, J6.1, J7.1, J8.1, J9.1, U1.15 (Vref), U1.16 (Vdd), U2.10 (~SRCLR), U2.16 (VCC), U4.16 (VCC)
AUX0: J19.2, R9.1, U4.11 (D0)
AUX1: J19.3, R10.1, U4.12 (D1)
AUX2: J19.4, R11.1, U4.13 (D2)
AUX3: J19.5, R12.1, U4.14 (D3)
AUX4: J19.6, R13.1, U4.3 (D4)
AUX5: J19.7, R14.1, U4.4 (D5)
AUX6: J19.8, R15.1, U4.5 (D6)
AUX7: J19.9, R16.1, U4.6 (D7)
FSR0: J2.2, R1.1, U1.1 (CH0)
FSR1: J3.2, R2.1, U1.2 (CH1)
FSR2: J4.2, R3.1, U1.3 (CH2)
FSR3: J5.2, R4.1, U1.4 (CH3)
FSR4: J6.2, R5.1, U1.5 (CH4)
FSR5: J7.2, R6.1, U1.6 (CH5)
FSR6: J8.2, R7.1, U1.7 (CH6)
FSR7: J9.2, R8.1, U1.8 (CH7)
GND: C1.2, C2.2, C3.2, C4.2, C5.2, C6.2, C7.2, C8.2, J1.6, J1.9, J1.14, J1.20, J1.25, J1.30, J1.34, J1.39, J18.2, J19.1, J19.10, R1.2, R2.2, R3.2, R4.2, R5.2, R6.2, R7.2, R8.2, R9.2, R10.2, R11.2, R12.2, R13.2, R14.2, R15.2, R16.2, U1.9 (DGND), U1.14 (AGND), U2.8 (GND), U2.13 (~OE), U3.9 (GND), U4.8 (GND), U4.10 (DS), U4.15 (~CE)
IN_CLK: J1.18, U4.2 (CP)
IN_QH: J1.22, U4.9 (Q7)
IN_SHLD: J1.16, U4.1 (~PL)
MOTOR0: J10.2, U3.18 (O1)
MOTOR1: J11.2, U3.17 (O2)
MOTOR2: J12.2, U3.16 (O3)
MOTOR3: J13.2, U3.15 (O4)
MOTOR4: J14.2, U3.14 (O5)
MOTOR5: J15.2, U3.13 (O6)
MOTOR6: J16.2, U3.12 (O7)
MOTOR7: J17.2, U3.11 (O8)
MOTOR_V+: C5.1, C8.1, J10.1, J11.1, J12.1, J13.1, J14.1, J15.1, J16.1, J17.1, J18.1, U3.10 (COM)
MTRDRV0: U2.15 (QA), U3.1 (I1)
MTRDRV1: U2.1 (QB), U3.2 (I2)
MTRDRV2: U2.2 (QC), U3.3 (I3)
MTRDRV3: U2.3 (QD), U3.4 (I4)
MTRDRV4: U2.4 (QE), U3.5 (I5)
MTRDRV5: U2.5 (QF), U3.6 (I6)
MTRDRV6: U2.6 (QG), U3.7 (I7)
MTRDRV7: U2.7 (QH), U3.8 (I8)
SPI_CE0: J1.24, U1.10 (~CS/SHDN)
SPI_MISO: J1.21, U1.12 (Dout)
SPI_MOSI: J1.19, U1.11 (Din)
SPI_SCLK: J1.23, U1.13 (CLK)
SR_RCLK: J1.13, U2.12 (RCLK)
SR_SER: J1.11, U2.14 (SER)
SR_SRCLK: J1.15, U2.11 (SRCLK)

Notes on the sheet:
ANALOG INPUT ZONE - 8 FSR note keys -> MCP3008 SPI ADC
MOTOR DRIVER ZONE - 74HC595 -> ULN2803A -> 8 vibration motors
DIGITAL INPUT EXPANSION (DNP) - socket fitted, populate later
RASPBERRY PI 3 INTERFACE
MOTOR_V+ is a separate supply rail. It shares ONLY GND with the 3.3V
logic domain and is never tied to +3V3.
All four ICs are socketed. Only U4 is DNP - its socket is fitted and its pulldowns R9-R16 and header J19 are populated, so the 74HC165 can be dropped in later without rework.

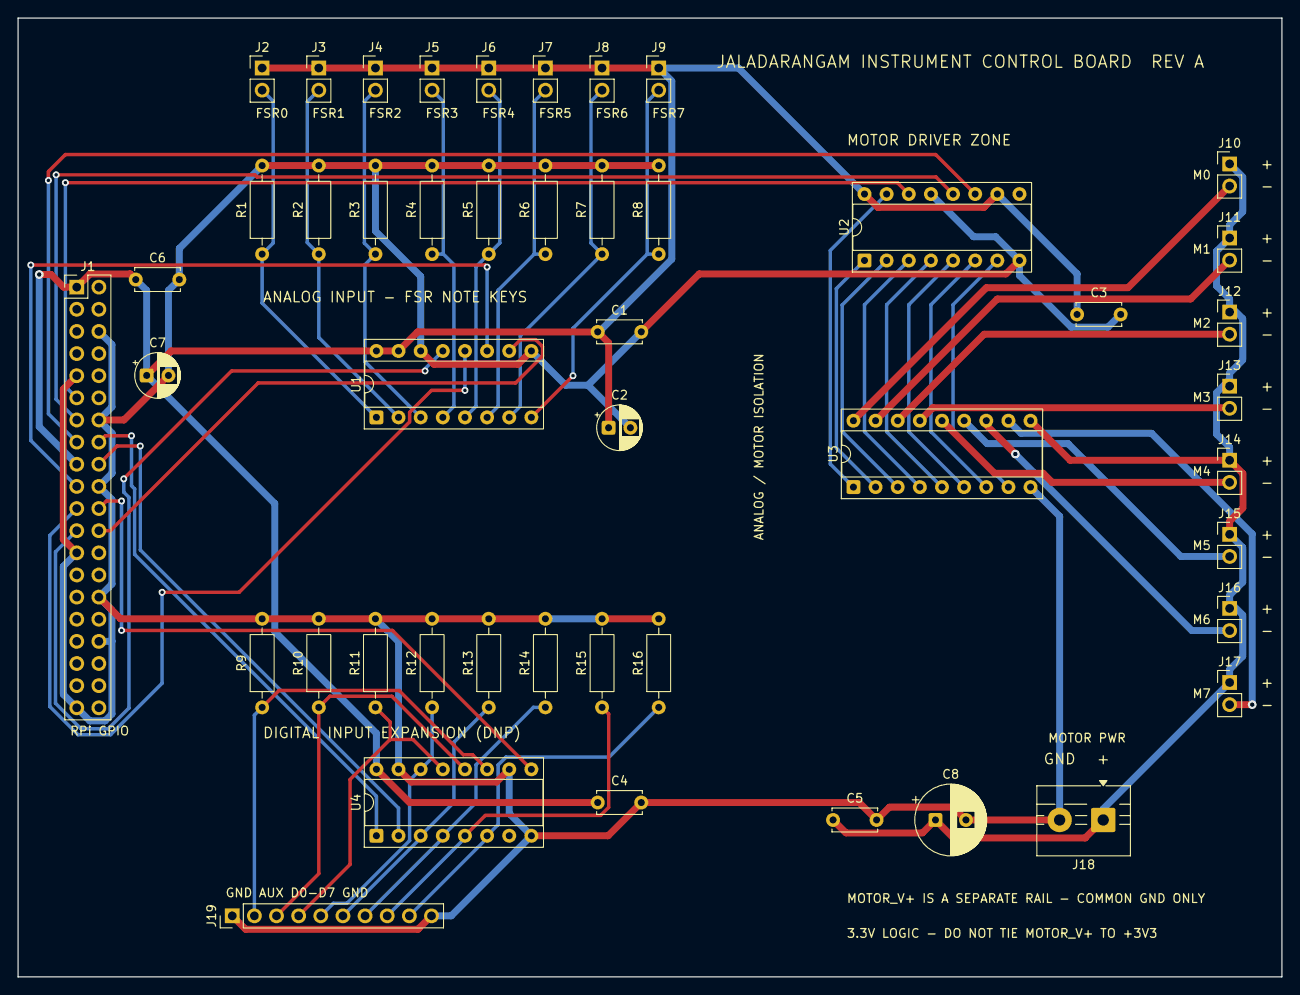
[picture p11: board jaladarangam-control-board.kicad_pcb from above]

Board: 2 copper layers, 145.0 x 110.0 mm, 47 parts (0 on the bottom side), 45 nets.

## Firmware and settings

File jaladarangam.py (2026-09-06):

#!/usr/bin/env python3
"""jaladarangam.py - the real hardware-driven instrument: 8 physical FSR
note keys on one MCP3008 (ADC1, raga-selectable positional layout, ported
from sliding_window_raga.py/gamaka_keyboard_mixer.py) plus 3 physical FSR
control keys (gamakam, octave+, octave-) read by an Arduino Nano 33 BLE
over USB serial, mandolin/guitar/flute instrument switching, the double
bass drone, the live 3-band EQ, and dual I2S+headphone output.

All 8 ADC1 keys (CH0..CH7) and all 3 Nano control keys (A0/A1/A2) are
physically wired with real FSRs - no keyboard stand-ins remain. No
vibration motors in this build (see key_press.py for that, on its own
throwaway test rig - unrelated to this instrument's hardware).

The control keys were originally planned as a second MCP3008 (ADC2) on
the same SPI0 bus as ADC1 (CE1 instead of ADC1's CE0). That chip turned
out to have an unresolved hardware fault: every channel (including one
never wired to anything) read an identical fixed value regardless of the
FSR, the pulldown, a direct ground jumper, which physical MCP3008 unit
was in the socket, or which chip-select line addressed it - conclusive
enough to rule out wiring and point at the chip itself. It was replaced
entirely with an Arduino Nano 33 BLE reading its own three analog FSRs
(A0=gamakam, A1=octave+, A2=octave-; A4/A5 avoided since they default to
this board's I2C bus) and streaming them as CSV over USB serial - see
control_keys/control_keys.ino and poll_nano_values below. No ADC2/CE1/
spidev code remains in this file.

The gamakam (jaru-trigger) key is now a real FSR (Nano A0), read
edge-triggered exactly like the ADC1 note keys (see poll_gamakam).
Octave+ / octave- (Nano A1 / A2) are also edge-triggered (debounced -
see poll_octave_keys) and shift the module-level `octave_shift`, which
every key position's pitch resolution (see resolve_position) is offset
by, clamped to +-OCTAVE_SHIFT_LIMIT.

POLYPHONY: the instrument is no longer monophonic. `voices` is a pool
of up to MAX_VOICES independently-playing voice dicts (one per
currently-ringing key position), each with its own sample position,
playback rate, and decay - all summed in audio_callback. A key's own
re-pluck replaces that same key's own prior voice (matching a real
instrument re-plucking its own string) rather than layering a second
copy of itself; a DIFFERENT key's pluck never touches another key's
voice. MAX_VOICES=8 matches the physical key count, so voice-stealing
(oldest-first - see pluck) is defense-in-depth for a future change
that might exceed that, not something normal 8-key play can trigger.
gamakam+jaru always acts on `most_recent_voice` (whichever voice was
plucked or last jaru'd most recently), matching a player having one
hand doing the glide motion regardless of how many other notes are
independently ringing.

OCTAVE-NEAREST PLUCK SELECTION: a normal pluck (not jaru) of Ri/Ga/Ma/
Pa/Da/Ni (positions 1-6) now lands in whichever octave (its own
default/structural one, one up, or one down) is nearest in pitch to
`most_recent_voice`'s pitch, via the same principle as nearest_octave_
hz - so e.g. playing upper Sa (key 8) then Ri (key 2) continues in the
upper register instead of dropping over an octave to Ri's default mid
position. Sa itself (position 0) and upper Sa (UPPER_SA_POSITION) are
deliberately EXCLUDED from this - they already have two dedicated,
unambiguous keys for their two registers, and applying nearest-pitch
there too would flip the traditional Ni->Sa cadence to resolve upward
instead of down (the leading-tone-to-tonic gap is mathematically
always the largest "improvement" nearest-pitch could find, so no
threshold can fix the Ri case without also flipping this one - see
this file's PR discussion for the worked-through math). The manual
octave+/octave- keys remain the explicit override for any case where
the automatic choice isn't the one intended.

ODUKKAL (pressure->pitch bend) and ATTACK VELOCITY: while a note key
is held and its voice is ringing, sustained pressure depth on that
SAME key bends its pitch up by 0-ODUKKAL_MAX_CENTS, smoothed via a
one-euro filter (see one_euro_filter) - same filter design as gamaka.
py's softpot smoothing, ported here for the same reason (a fixed-alpha
EMA lags fast pressure changes badly). Toggled on/off via 'o'+Enter
(default OFF); when off, pressure has zero effect on pitch. This is
purely additive on top of whatever jaru/octave-shift state a voice
already has (see audio_callback's rate composition), never a
replacement, mirroring gamaka.py's kampita-is-additive-to-jaru
design. Independent per voice, since each voice has its own filter
state and its own key's pressure feeds only its own bend.

Separately (NOT gated by the odukkal toggle - always active), the
rate of pressure rise at a fresh pluck's press-edge (dF/dt, measured
in raw ADC counts/sec) maps to attack velocity via velocity_to_params,
currently scaling amplitude only, since only one mandolin stress-level
recording exists on disk today (see mandolin_audio.STRESS_LEVEL) -
that function returns a dict specifically so a future 'layer' key can
drive real low/high-stress sample selection without restructuring any
caller.

PER-INSTRUMENT ENVELOPE: mandolin/guitar are 'plucked' - attack on
press-edge, then ring through their own natural decay regardless of
release, exactly as this file has always behaved. flute is 'sustained'
- attack the same way, but release stops the note promptly (a 50ms
fade, FLUTE_RELEASE_SECONDS, to avoid a click) instead of letting it
play out. A voice's envelope is fixed at pluck time from the actual
resolved source_used (so a flute pluck that falls back to a guitar
sample - outside flute's recorded range - correctly gets plucked
behavior, since what's actually ringing is a guitar recording). Real
sustain/looping was considered (see ENVELOPE_MODES/FLUTE_RELEASE_
SECONDS section) and deliberately not implemented: the flute samples'
RMS envelope does show a genuine ~2-2.5s quasi-steady region, but with
real breath/vibrato variation rather than a flat plateau, so a loop
point picked without per-note listening/tuning risks an audible seam -
worse than just letting each note play its natural (already fairly
long) recorded length while held.

NETWORK CONTROL: every toggle/config command (drone, instrument
source, EQ, dual output, odukkal, volume) is a standalone function
(toggle_drone, set_source, adjust_band, etc.) with no stdin-specific
logic - control_listener (stdin), run_network_server (WiFi, a
WebSocket server on NETWORK_PORT), and run_bluetooth_server (a
Bluetooth SPP/RFCOMM server, "Just Works"/no-PIN pairing) are three
different ways a command can ARRIVE, each in its own thread so none of
control_loop's real-time SPI/serial polling, the WiFi asyncio loop, or
the Bluetooth D-Bus/GLib loop can block each other. All three funnel
through the same _dispatch_command/NETWORK_COMMANDS layer and every
one triggers the exact same broadcast_state() push of the full current
state to every connected client on BOTH network transports, regardless
of which transport (or stdin) triggered the change. Full JSON protocol
(every command, its fields, the state-push shape, both transports) is
documented in PROTOCOL.md - that's the contract to build a client
against, not this file.

NOTE: an earlier revision of this file used a FIXED Sa-Ri-Ga-Ma-Pa-Da-
Ni-Sa' diatonic layout (natural-major swara values) instead of raga
selection. This revision replaces that entirely per updated
requirements - the note map is now positional and raga-driven, matching
gamaka_keyboard_mixer.py's "Mode B" fingering, not a fixed scale.

A tanpura drone layer ('t'+Enter) was scoped for this revision but is
NOT implemented: no suitable sample could be sourced within this file's
license requirement (explicitly free for any use, no attribution-only/
personal-use-only restriction) that was also actually downloadable -
Freesound had a confirmed CC0 tanpura recording but gated the download
behind account login; a Pixabay mirror of the same recording had no
login wall but is blocked by Cloudflare bot-protection from this
environment's tools. Dropped per instruction rather than substituted
with a lower-quality or license-uncertain source. Because of this, 't'
as a stdin command is unused in this file - the collision concern
raised about physical note-key input doesn't apply anyway, since this
file's note keys are FSRs read over SPI (ADC1) and its control keys are
FSRs read via the Arduino Nano over USB serial; no code in this file
reads the keyboard for performance input at all.

Provenance of each piece (this file's own PR description/conversation
has the full detail; summarized here):
  - Sample loading, single-voice variable-rate playback, ramp/portamento
    math, and the bass-boost-capable output stage: mandolin_audio.py
    (shared engine, used unchanged by every script in this project).
  - Raga corpus loading, distinct-pitch-set derivation (arohanam UNION
    avarohanam, deduplicated, sorted ascending from Sa), and the
    position<->semitone/swara math with automatic next-octave
    continuation for positions past a short raga's pattern length:
    ported from sliding_window_raga.py (this file's note_to_index/
    index_to_note/load_raga_corpus/find_raga/strip_trailing_sa/
    distinct_pitch_set/position_to_semitones/position_to_swara are
    copies of that file's functions, not imports - matching this
    project's existing convention of each script being self-contained
    apart from mandolin_audio.py; gamaka_keyboard_mixer.py made the same
    choice for the same functions).
  - Key 8 (position 7) forced to always be upper Sa regardless of the
    raga's pattern length: NEW in this file. Neither
    sliding_window_raga.py nor gamaka_keyboard_mixer.py has an 8th key -
    both let positions past the pattern length continue wrapping via the
    generic position_to_semitones formula (which for a short/pentatonic
    raga would NOT land back on Sa at position 7). See
    UPPER_SA_POSITION's resolve_position handling.
  - Jaru-target nearest-octave selection: NEW in this file (see
    nearest_octave_hz) - no prior script has octave-aware jaru. Only
    the Sa->Ri direction has been tested against real hardware; every
    other key-to-key jaru, and any case where the nearest octave is
    "down" rather than "up," remains UNTESTED.
  - Instrument switching (mandolin/guitar/flute cycling, positional
    MandolinBank, ChromaticBank nearest-note lookup, missing-note
    fallback-to-guitar policy): ported from gamaka_keyboard_mixer.py's
    resolve_note/MandolinBank/ChromaticBank essentially unchanged, just
    renamed resolve_position and extended to 8 positions (5 recorded
    mandolin positions, 3 fallback positions: 5, 6, and the fixed
    upper-Sa position 7).
  - Double bass drone (C#1/C#2, 'b'/'c'): gamaka_keyboard.py, unchanged.
  - 3-band EQ (bass/mid/treble): gamaka_keyboard_mixer.py, unchanged.
  - Dual I2S+headphone output ('s'): gamaka_keyboard_mixer.py, unchanged.
  - Control-key integration (gamakam, octave+, octave-) and the
    `octave_shift` mechanism: NEW in this revision, replacing the
    keyboard-spacebar gamakam stand-in entirely. Octave shift concept
    (a signed integer that offsets every key's resolved pitch by whole
    octaves) ported from sliding_window_raga.py's manual-octave-key
    handling; here it's driven by real FSRs instead of keyboard keys,
    and applies uniformly to all 8 ADC1 positions via resolve_position
    rather than to a positional swara pattern. Originally built against
    a second MCP3008 (ADC2); rebuilt against an Arduino Nano 33 BLE over
    USB serial after ADC2 proved to have an unresolved chip-level fault
    (see the module docstring's opening section). octave_shift is
    clamped to +-OCTAVE_SHIFT_LIMIT on every increment/decrement, and
    resolve_position's dynamically-computed rate is separately clamped
    to [RATE_MIN, RATE_MAX] as defense-in-depth - both fixes were added
    after a runaway octave_shift (from then-undebounced, then-unbounded
    octave keys) was diagnosed as the cause of a "very low pitch /
    heavy speaker vibration" bug, and both are kept here even though the
    input source changed, since the failure mode they guard against
    (an extreme target_hz collapsing playback rate toward zero) doesn't
    depend on which hardware drives octave_shift.
  - Polyphony (the `voices` pool, voice-stealing, per-voice glide/
    odukkal state), octave-nearest pluck selection (Sa/upper-Sa
    excluded - see module docstring), odukkal pressure->bend, and
    attack velocity: NEW in this revision. The single global
    `active_voice`/`glide` model is gone entirely, replaced by a list
    of independent voice dicts; jaru's cents-ramp math (ramp_cents,
    cents_between, nearest_octave_hz) is unchanged, just now reads/
    writes `most_recent_voice` and a per-voice 'glide' field instead
    of module globals. odukkal reuses gamaka.py's one-euro filter
    design (ONE_EURO_* constants/tuning) verbatim, one filter instance
    per voice rather than one shared instance, since two held keys'
    pressure must never leak into each other's bend.
  - Per-instrument envelope (plucked vs sustained), flute's release
    fade: NEW in this revision. A voice's envelope mode and release
    state ('envelope', 'releasing', 'release_start') are new per-voice
    fields alongside the polyphony fields above; the fade itself
    (audio_callback) is a plain per-frame linear gain ramp, sample-
    accurate against real elapsed time rather than block-quantized, so
    the short (50ms) duration stays smooth regardless of BLOCKSIZE
    boundaries. True crossfaded sample looping for the sustain portion
    was considered and deliberately not implemented - see module
    docstring for the reasoning (real vibrato/breath variation in the
    samples' sustain region makes a blind loop point risky).
  - Network control (run_network_server, NETWORK_COMMANDS, broadcast_
    state, get_full_state) and master volume (master_volume, set_
    volume/adjust_volume - no volume control existed before this):
    NEW in this revision. Refactored set_source out of cycle_source
    (previously one function that always advanced; now cycle_source is
    a one-line wrapper over set_source, which the network layer's
    direct instrument-select command also calls) so every command has
    exactly one implementation regardless of which transport triggered
    it. No tanpura toggle exists in the network protocol, matching the
    module docstring above - there is no tanpura feature in this file
    to expose.
  - Bluetooth SPP transport (run_bluetooth_server, _BluetoothProfile,
    _BluetoothAgent, _handle_bt_client) and the _dispatch_command
    refactor it required: NEW in this revision. _dispatch_command was
    factored out of what used to be _handle_ws_message's body so both
    the WebSocket and Bluetooth handlers call one shared implementation
    instead of two copies of the same JSON-parsing/NETWORK_COMMANDS-
    lookup/error-formatting logic - this is also what "reuse
    NETWORK_COMMANDS directly" meant in practice, not just dispatching
    through the same table but sharing the code around it too. Uses
    dbus-python + PyGObject's GLib (both already on Raspberry Pi OS) to
    talk to BlueZ's own D-Bus API, not PyBluez - see run_bluetooth_
    server's docstring for why (PyBluez is unmaintained; the classic
    sdptool-based approach doesn't work on this system's BlueZ at all).
    broadcast_state was generalized from WebSocket-only to fan out to
    both transports (_broadcast_ws_async, _broadcast_bt) - a Bluetooth
    client sees a state change made from WiFi or stdin exactly as
    promptly as a WebSocket client would, and vice versa.

Usage:
    python3 jaladarangam.py --raga Shankarabharanam
"""
import argparse
import asyncio
import collections
import json
import os
import socket
import sys
import threading
import time
import numpy as np
import soundfile as sf
import sounddevice as sd
import serial
from serial.tools import list_ports
import spidev
import mandolin_audio as ma
from mandolin_audio import SAMPLE_RATE, BLOCKSIZE

try:
    import websockets
except ImportError:
    # Network control degrades gracefully to unavailable - stdin control
    # (control_listener) still works fully either way. On Debian/Raspberry
    # Pi OS, `sudo apt install python3-websockets` provides this without
    # needing pip/venv (this system's Python is externally-managed, PEP
    # 668) - that's the path this project's Pi actually used.
    websockets = None

try:
    import dbus
    import dbus.mainloop.glib
    import dbus.service
    from gi.repository import GLib
except ImportError:
    # Bluetooth control degrades gracefully to unavailable, same as
    # websockets above - stdin and WiFi control are unaffected. PyBluez
    # (the obvious first guess) was deliberately NOT used here: it's
    # packaged for Debian/Raspberry Pi OS (`python3-bluez`) but that
    # package is literally PyBluez's last-ever upstream release (0.23,
    # ~2018) with no real maintenance since. dbus-python + PyGObject's
    # GLib (both already present on Raspberry Pi OS - no extra install
    # needed) talking to BlueZ's own D-Bus API is the current, actually-
    # maintained way to do this; the legacy sdptool/hciconfig approach
    # some older PyBluez tutorials use doesn't work on this system at
    # all (bluetoothd runs without --compat, confirmed via `sdptool
    # browse local` failing outright).
    dbus = None
    GLib = None

# --- Hardware: all 8 keys physically wired on one MCP3008 (CH0..CH7 =
# position 0..7). Positions are ALSO the MCP3008 channel numbers directly -
# no separate name/channel table needed. Add/remove entries here if a key
# is ever unwired again.
LIVE_POSITIONS = set(range(8))

CONTROL_INTERVAL = 0.02  # seconds between SPI poll rounds, same as gamaka.py
PRESS_THRESHOLD = 100    # raw ADC counts (0-1023) - validated against real
                         # Sa/Ri hardware in key_press.py. ADC1 note keys
                         # only - the control keys have their own threshold
                         # below (NANO_PRESS_THRESHOLD), since they're now
                         # read by different hardware with its own noise
                         # floor/range, not this same MCP3008.

# --- Arduino Nano 33 BLE: control keys (gamakam, octave+, octave-) --------
# Replaces the second MCP3008 (ADC2) entirely - see module docstring for
# why. A0=gamakam, A1=octave+, A2=octave- on the Nano; A4/A5 avoided since
# they default to this board's I2C bus. Firmware: control_keys/
# control_keys.ino, which streams "gamakam,octave_up,octave_down\n" once
# per ~20ms over USB serial.
NANO_VID = 0x2341
NANO_PID = 0x805A
NANO_FALLBACK_PORT = '/dev/ttyACM0'  # used only if VID/PID auto-detection
                                     # (find_nano_port) finds nothing - the
                                     # port is not assumed stable across
                                     # reboots/reconnects otherwise.
NANO_BAUD = 115200

NANO_PRESS_THRESHOLD = 100  # raw analogRead counts (0-1023 - the Nano's
                            # analogRead defaults to the same 10-bit range
                            # as the MCP3008s). Bench-tested directly
                            # against these three specific FSRs (not
                            # assumed from the note-key threshold above):
                            # idle reads 0-4, presses climb smoothly to
                            # 850-950+, so 100 leaves wide margin on both
                            # sides of this particular hardware's range.

OCTAVE_SHIFT_LIMIT = 2  # +-2 octaves - enough range to be musically useful,
                        # tight enough that a runaway octave_shift (bug,
                        # debounce failure, etc.) can't collapse resolve_
                        # position's target_hz toward zero. Clamped on every
                        # increment/decrement in poll_octave_keys, not just
                        # capped after the fact.

OCTAVE_DEBOUNCE_POLLS = 5  # consecutive above-threshold polls (~100ms at
                            # CONTROL_INTERVAL=0.02s) required before an
                            # octave+/octave- reading counts as a real press
                            # (see _debounced_press). Guards against a raw
                            # value that wobbles across NANO_PRESS_THRESHOLD
                            # (sensor noise, marginal contact) registering as
                            # several spurious edges during one physical
                            # press-and-hold - each edge permanently shifts
                            # octave_shift, unlike a note-key false retrigger
                            # (harmless re-pluck), so only the octave keys
                            # need this. Kept even though the old ADC2 chip
                            # (the original reason this was added) is gone -
                            # cheap insurance against any future sensor
                            # noise on this path, same as the clamps above.

RATE_MIN = 0.5  # -1 octave from the sample's own measured pitch
RATE_MAX = 2.0  # +1 octave - clamps resolve_position's dynamic rate
                # calculation so that even if target_hz is ever extreme
                # (octave_shift misbehaving or otherwise), playback rate
                # physically cannot collapse toward silence-via-near-zero
                # or spike to an ear-damaging pitch. Defense-in-depth on
                # top of the octave_shift clamp above, not a replacement
                # for it. Also the final clamp on the odukkal-combined
                # rate in audio_callback - see MAX_VOICES section below.
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

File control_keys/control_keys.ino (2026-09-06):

// Reads the three ADC2-replacement control-key FSRs (gamakam, octave+,
// octave-) on A0/A1/A2 and prints them as CSV each cycle, for
// jaladarangam.py to parse over serial: "gamakam,octave_up,octave_down\n".
// A4/A5 are intentionally unused - reserved for this board's I2C bus.
// This supersedes a0_raw_test.ino (single-channel bring-up test) now that
// all three channels are wired and validated individually.
void setup() {
  Serial.begin(115200);
}

void loop() {
  int gamakam = analogRead(A0);
  int octave_up = analogRead(A1);
  int octave_down = analogRead(A2);
  Serial.print(gamakam);
  Serial.print(',');
  Serial.print(octave_up);
  Serial.print(',');
  Serial.println(octave_down);
  delay(20);
}

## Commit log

2026-08-21 Add spacebar PoC and MCP3008 sensor wiring documentation
    Includes the evdev+pygame keyboard-trigger proof of concept, the CC0
    guitar sample it uses, and a verified wiring guide (against the Pi
    GPIO pinout and MCP3008 datasheet) for the real FSR/SoftPot sensor
    hardware to be wired next.
2026-08-22 Add MCP3008 sensor test scripts and gamaka pitch-bend proof of concept
    - read_fsr_raw.py / fsr_oscillator.py: verify FSR wiring and map pressure
    to pitch via a persistent pygame oscillator (interface-level test).
    - gamaka.py: sounddevice-based engine that triggers a D3/G3 guitar pluck
    per FSR and bends pitch 0-40 cents with pressure, using EMA-smoothed
    ADC and variable-rate linear-interpolation playback for continuous bend.
    - prepare_samples.py + d3_pluck.wav/g3_pluck.wav: CC0 samples derived from
    karoryfer.shinyguitar (Eb3/Gb3, pitch-shifted 1 semitone to D3/G3).
    [fsr_oscillator.py, gamaka.py, prepare_samples.py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]
2026-08-23 Add 7-key raga prototype with auto octave rollover
    Keyboard stand-in for the eventual 7-FSR instrument: 7 note keys map
    positionally to a raga's distinct pitch set (arohanam union avarohanam,
    not arohanam alone), with automatic octave rollover on strict key7<->key1
    adjacency and manual override keys. Replaces an earlier two-mode A/B
    prototype after live testing showed the auto-rollover design worked
    correctly in both directions and under rapid toggling.
    Includes a 19-raga Carnatic corpus (ragas.json), cross-verified against
    independent sources per raga, and a placeholder guitar sample set
    (University of Iowa MIS, free-use license verified) standing in for the
    mandolin while it's away for re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
    [sliding_window_raga.py]
2026-08-25 Add mandolin_audio shared engine, gamaka_keyboard prototypes, and double bass/flute sample sources
    Extracts gamaka.py's sample loading, pitch detection, variable-rate
    playback, and output stage (bass boost + gain + clip) into a shared
    mandolin_audio module, so gamaka_keyboard.py (keyboard-driven single-
    voice player with jaru and a double bass drone) and
    gamaka_keyboard_mixer.py (adds a live 3-band EQ, dual I2S+headphone
    output, and a 7-key positional raga fingering engine with a 3-way
    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
2026-09-06 Add jaladarangam.py: 8-key hardware instrument, document ADC2 wiring and correct stale SoftPot references
    jaladarangam.py is the real hardware-driven instrument, reading all 8 note-key
    FSRs on ADC1 (CH0-CH7 = Sa..Sa', all physically wired and confirmed working).
    Implemented: raga selection (--raga), octave-aware jaru glide (spacebar stands
    in for the not-yet-wired gamakam key), mandolin/guitar/flute instrument
    switching, the double bass drone, live 3-band EQ, and dual I2S+headphone
    output.
    Known limitations:
    - Jaru is only validated against real hardware for the Sa->Ri direction; other
    key-to-key pairs and octave-down landings are implemented but untested.
    - Tanpura drone was scoped but N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
    [jaladarangam.py]
2026-09-06 Replace faulty ADC2 with an Arduino Nano 33 BLE for gamakam/octave keys
    The second MCP3008 (ADC2) planned for the three control keys had an
    unresolved hardware fault: every channel - including one never wired to
    anything - read an identical fixed value regardless of the FSR, the
    pulldown, a direct ground jumper, which physical chip was in the socket,
    or which chip-select line addressed it. That combination of tests ruled
    out wiring and pointed at the chip itself, so ADC2 is replaced entirely
    rather than debugged further.
    An Arduino Nano 33 BLE now reads its own three analog FSRs (A0=gamakam,
    A1=octave+, A2=octave-; A4/A5 avoided since they default to this board's
    I2C bus) and streams them a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
    [control_keys.ino, jaladarangam.py]
2026-09-06 Add polyphony, octave-nearest plucks, odukkal, velocity, and per-instrument envelopes
    Polyphony: replaced the single global active_voice/glide model with a
    voice pool (up to MAX_VOICES=8, matching the physical key count). Each
    key maps to at most one voice; a key's own re-pluck replaces its own
    prior voice (matching a real instrument re-plucking its own string), a
    different key's pluck never touches another key's voice. Voice-stealing
    (oldest-first) is defense-in-depth for a pool overflow that normal
    8-key play can't actually trigger. gamakam+jaru always acts on
    most_recent_voice, regardless of how many other voices are ringing.
    Octave-nearest pluck selection: Ri/Ga/Ma/Pa/Da/Ni now land in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
    [jaladarangam.py]
2026-09-06 Add WebSocket network control interface alongside existing stdin commands
    Refactored every toggle/config command (drone, instrument source, EQ,
    dual output, odukkal) into standalone functions with no stdin-specific
    logic - stdin (control_listener) is now just one caller of these, on
    equal footing with a new WebSocket layer (run_network_server, on
    NETWORK_PORT=8765, started in its own thread/event loop so it never
    adds latency to the real-time SPI/serial control loop). Added a master
    volume control (set_volume/adjust_volume) that didn't exist before,
    via the same pattern.
    Every command, regardless of which transport it arrived on, pushes the
    full current state (instrument, drone, EQ, odukkal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
    [jaladarangam.py]
2026-09-06 Add Bluetooth SPP transport alongside WiFi, run persistently via systemd
    Registers a Classic Bluetooth (SPP/RFCOMM) server via BlueZ's own D-Bus
    API (org.bluez.ProfileManager1 + AgentManager1), not PyBluez - verified
    PyBluez's Debian package (python3-bluez) is literally its last-ever
    upstream release (0.23, ~2018) with no real maintenance since, and
    confirmed the legacy sdptool/hciconfig approach doesn't work on this
    system's BlueZ at all (bluetoothd runs without --compat). dbus-python +
    PyGObject's GLib (both already on Raspberry Pi OS) plus Python's
    built-in socket.AF_BLUETOOTH for the actual RFCOMM I/O needed no new
    packages. Pairing is "Just Works" (NoInputNoOutput agent) - no PIN.
    Fact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
    [jaladarangam.py]
2026-09-06 Add STATUS.md and fix stale ADC2 references in README.md
    No code changes this commit - this session's Bluetooth SPP work (both
    transports, systemd persistence, the missing-SDP-registration/non-
    blocking-fd fixes, end-to-end Android validation) was already committed
    and pushed as 6411ce7 in the previous turn; confirmed via git status on
    the Pi that nothing further had drifted since.
    Added STATUS.md: a standalone "what's done / what's not / what's next"
    snapshot for resuming work cleanly later, covering current hardware
    (ADC1 8-key, ADC2 retired in favor of the Nano), current jaladarangam.py
    features (polyphony, octave-nearest note selection with the Sa/upper-Sa
    exclusion and why, odukkal, at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
2026-09-19 Add fully-routed, fabrication-ready KiCad hardware project
    First fully-routed, fabrication-ready version of the Jaladarangam
    Instrument Control Board: Raspberry Pi 3 -> MCP3008 SPI ADC for 8 FSR
    note keys, and 74HC595 -> ULN2803A driving 8 vibration motors, with a
    socketed-but-DNP 74HC165 digital input expansion. 145 x 110 mm, 2 layer,
    through-hole, all four ICs socketed.
    Everything is generated from scripts/board_spec.py as the single source
    of truth - components, pin-to-net assignments, placement, design rules
    and net classes. The schematic, PCB, project file and BOM are all
    derived from it, so the wiring has only one place to live. Three
    scripts reproduce the whole thing: build.sh, route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
    [board.dsn, bom.csv, bom_kicad.csv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]
2026-09-19 Add tracked review images: 3D, 2D layout, and silkscreen close-ups
    Adds hardware/review/ with ten PNGs so the routed board can be inspected
    without opening KiCad or being at the machine that built it, plus
    scripts/make_review.sh to regenerate them.
    3D renders (isometric, top, bottom) now show real component bodies. The
    lite KiCad AppImage ships no 3D model packages, so a full extract was
    added alongside it; kienv.sh points KICAD10_3DMODEL_DIR at it when
    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
2026-09-20 Export the schematic into review/, and make review/ the single home for renders
    Adds the schematic to the review folder alongside the board images, via
    KiCad's own exporter (kicad-cli sch export pdf), not a screenshot.
    The schematic goes out as PDF first: it stays vector, so this board's
    dense single A2 sheet reads at any zoom, which a raster cannot match.
    A 300 dpi PNG sits beside it for a quick look without a PDF reader -
    7016x4961, which puts the 1.27 mm net labels at 15 px and keeps them
    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
2026-09-20 Mark J18 polarity on silkscreen, and fix a module ordering bug
    Adds "+" and "GND" to the silkscreen above the motor supply input,
    each centred over the pad it labels. J18 carries a separate, possibly
    higher-voltage rail, and connecting it backwards would drive MOTOR_V+
    straight onto the board's ground net; the pad-1 square marker alone did
    not say which pin was which.
    The change is silkscreen-only in electrical terms - J18's pads stay at
    (124.50, 92.00) and (119.50, 92.00), the footprint is untouched and no
    copper moved. It was still routed through board_spec.py and the full
    pipeline rather than patched into the .kicad_pcb, because gen_pcb.py
    rebuilds the board from the spec on every run an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
    [board.dsn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]
2026-09-20 Mark motor header polarity, and verify marks against placed pads
    Adds "+" and "-" to the silkscreen at J10-J17, in the clear board margin
    outboard of each pad: "+" beside pin 1 on MOTOR_V+, "-" beside pin 2 on
    that channel's ULN2803A output. Their pins stack 2.54 mm apart, too
    close to caption from above the way J18's side-by-side pins are, so the
    marks go outboard instead.
    This completes the polarity marking started at J18. Every pin carrying
    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
    [board.dsn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]
